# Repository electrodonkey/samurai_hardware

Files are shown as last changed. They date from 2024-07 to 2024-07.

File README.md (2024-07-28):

# samurai_hardware
Sumo Robot - Main Board

## Description

This repository contains the hardware design files for the main board of the HIRO 2024 sumo robot. The main board is responsible for the following tasks:

- Running the control algorithm
- Optical sensor reading
- Reading IMU data
- Communicating with the motor drivers

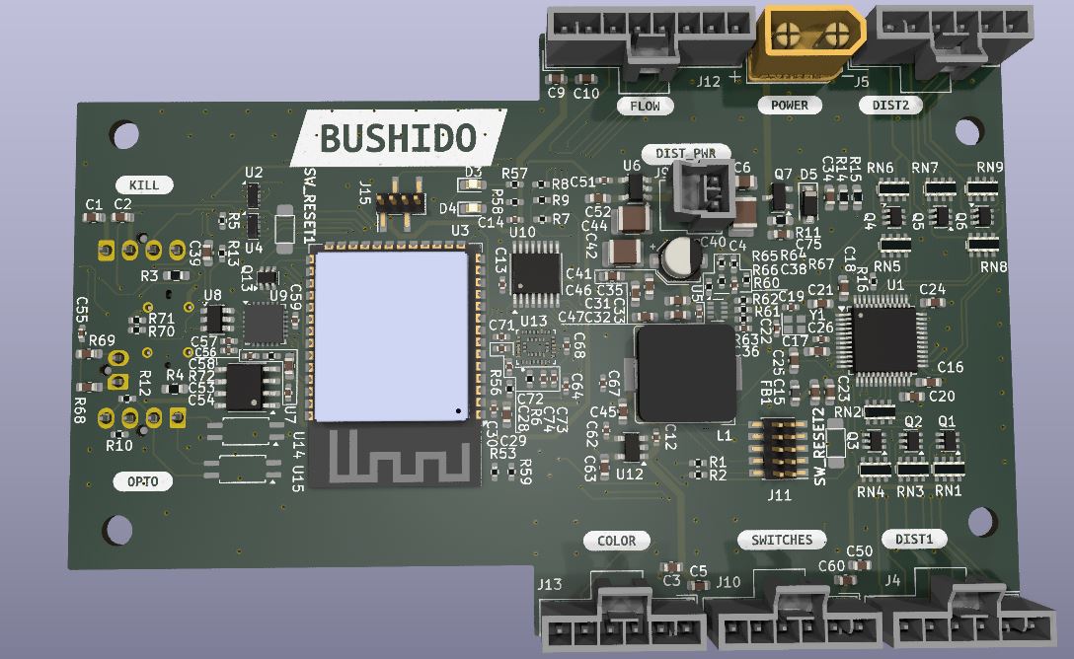
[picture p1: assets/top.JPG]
Top


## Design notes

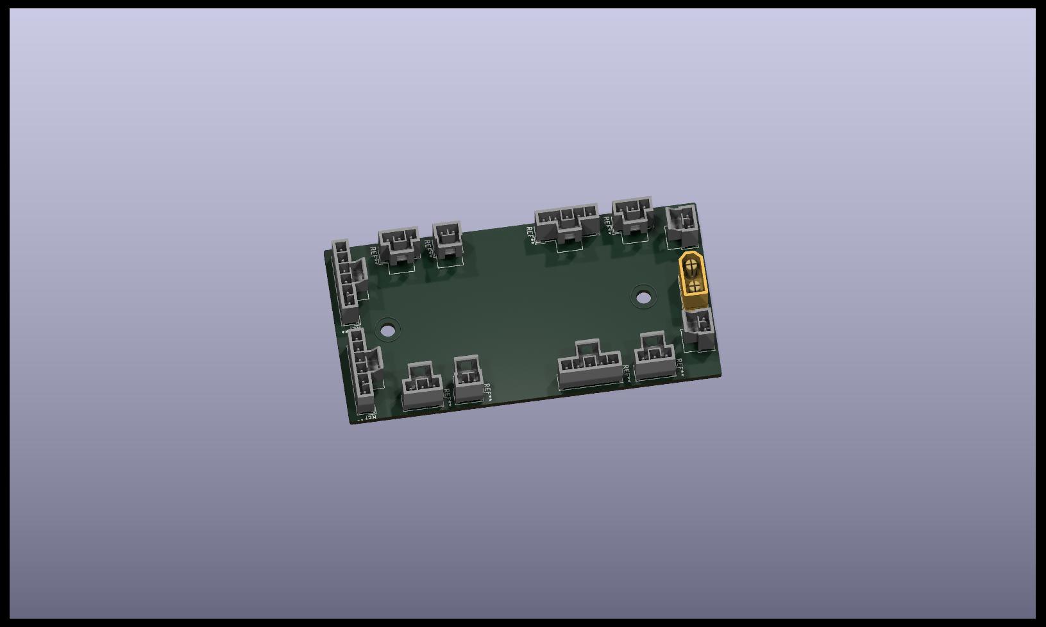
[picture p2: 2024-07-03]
samurai_connector_placement1.jpg

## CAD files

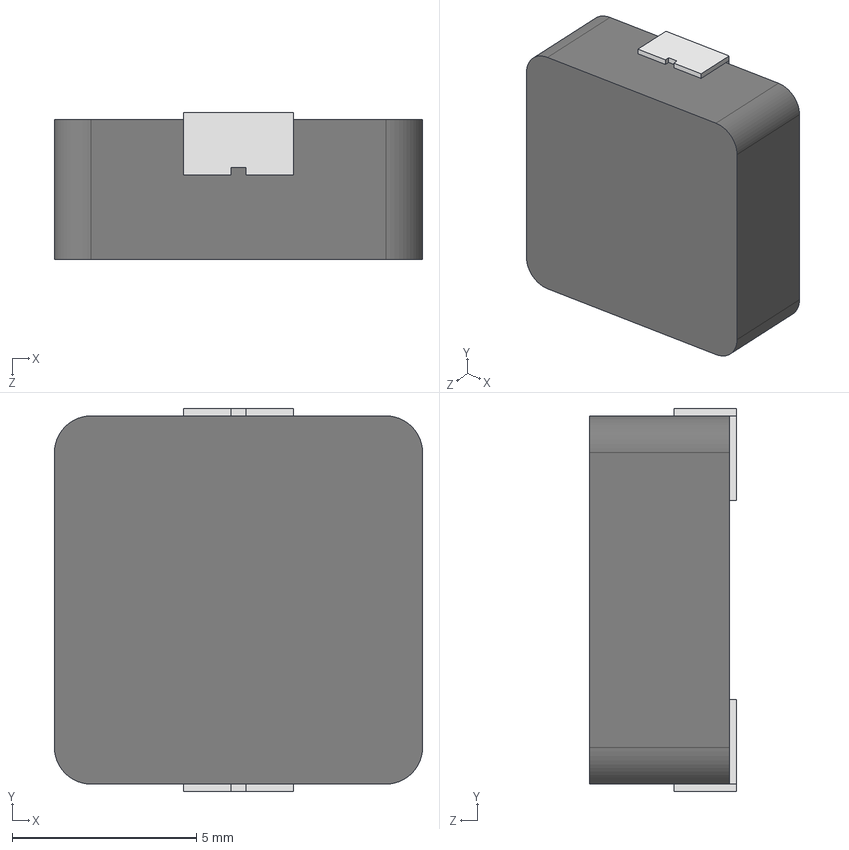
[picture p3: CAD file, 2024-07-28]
3d/User Library-SRP 1038A.step
10.0 x 10.4 x 4.00 mm

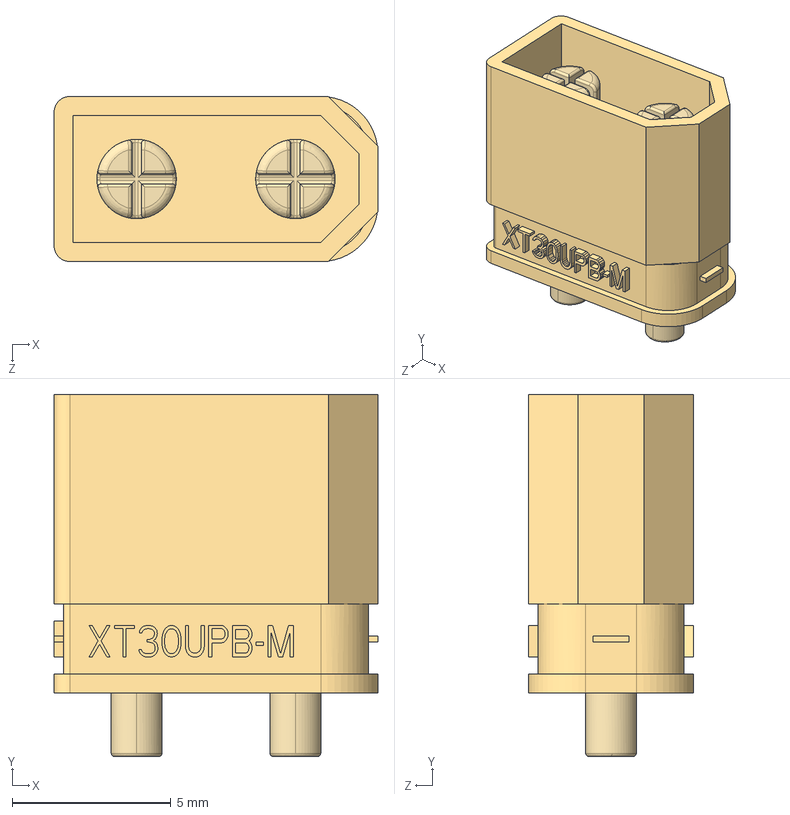
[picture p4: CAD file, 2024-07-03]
3d/amass-xt30upb-m.STEP
10.2 x 11.4 x 5.20 mm
XT30UPB-M
XT30UPB-M-PIN x 2

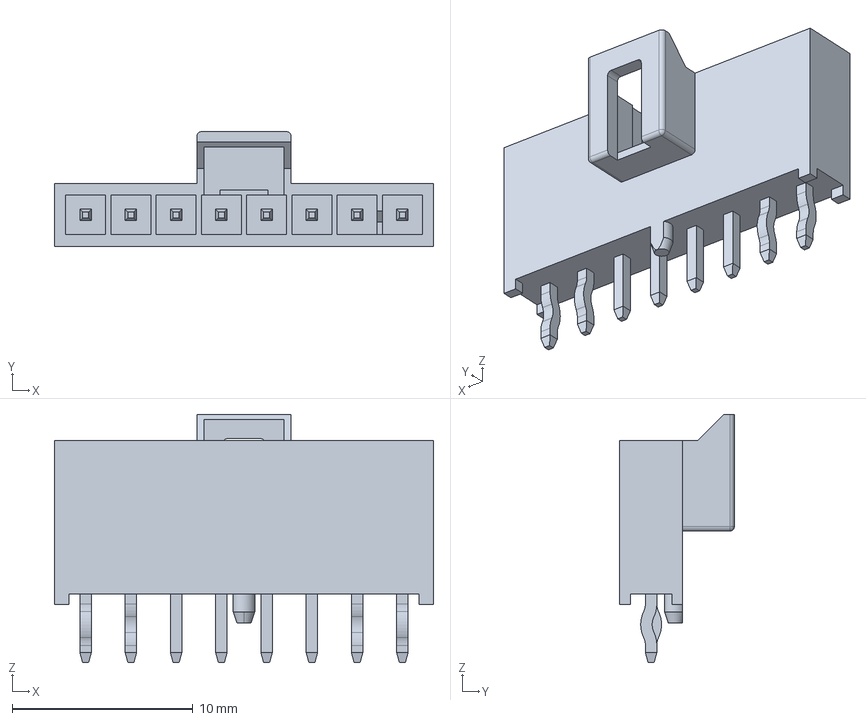
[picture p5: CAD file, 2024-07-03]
3d/molex_nanofit_1053091108.stp
20.9 x 6.34 x 13.7 mm

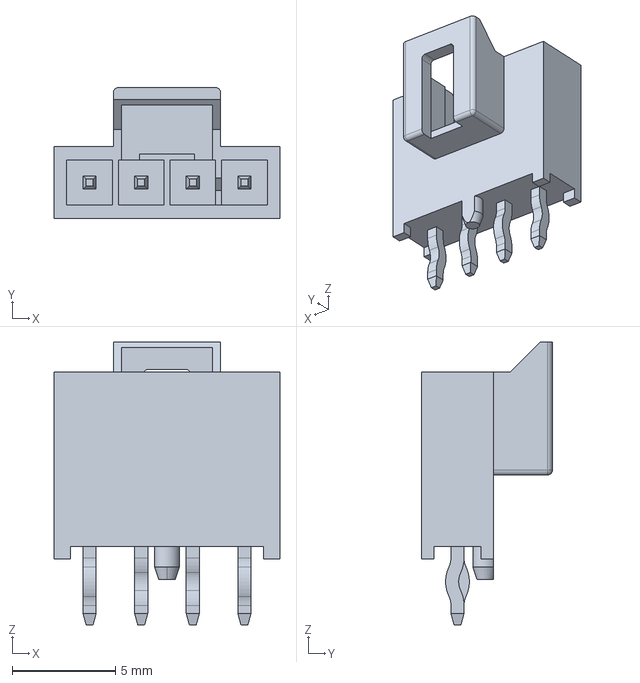
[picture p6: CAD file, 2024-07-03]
3d/molex_nanofit_1053091104.stp
10.9 x 6.34 x 13.7 mm

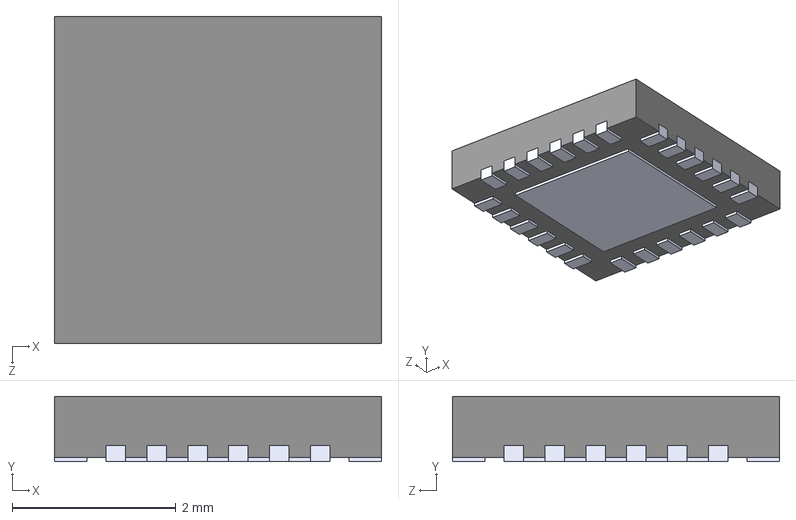
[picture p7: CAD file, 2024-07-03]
3d/CP2105-F01-GM.STEP
4.00 x 0.8 x 4.00 mm

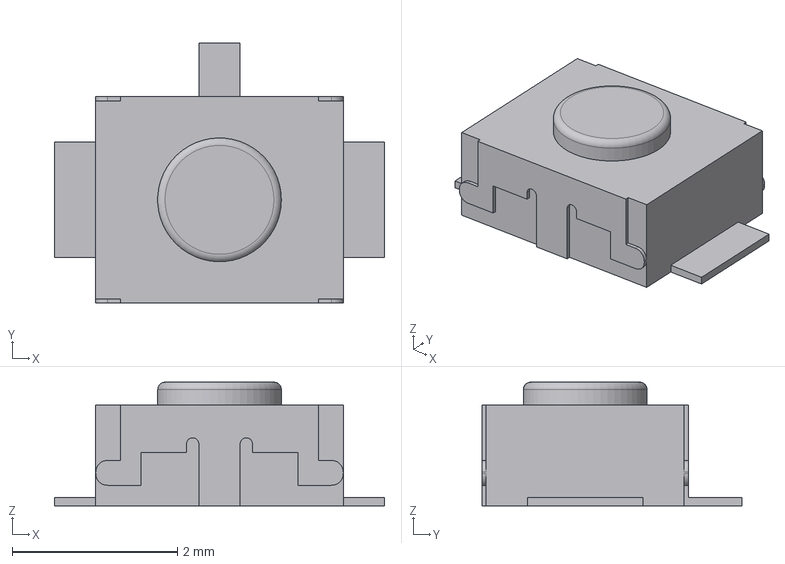
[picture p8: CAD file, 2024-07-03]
3d/TL1017AABF260QG.stp
4.00 x 3.15 x 1.50 mm

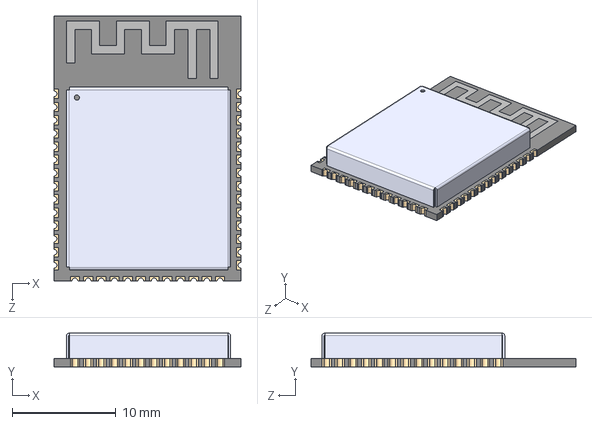
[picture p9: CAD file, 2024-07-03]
3d/ESP32-S3-WROOM-2-N16R8V--3DModel-STEP-510211.STEP
18.0 x 3.25 x 25.5 mm

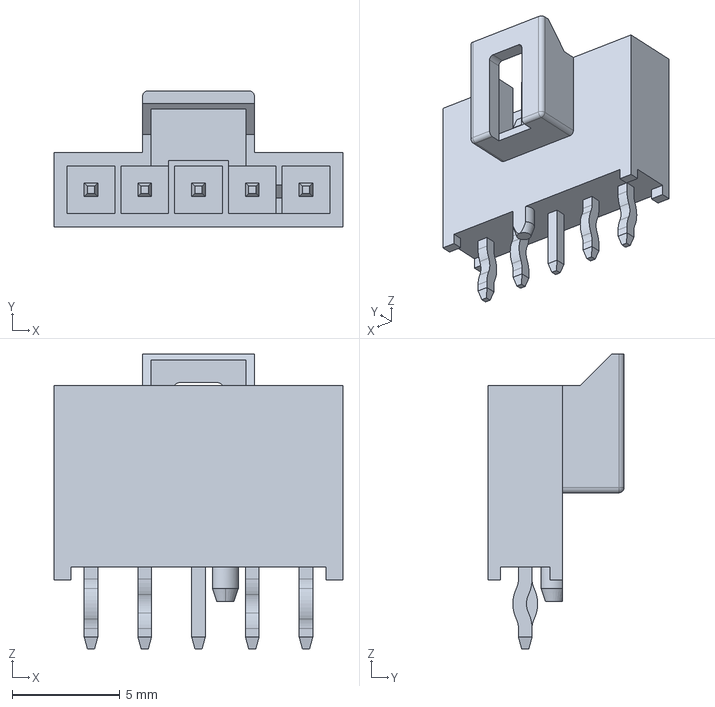
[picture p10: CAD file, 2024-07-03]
3d/molex_nanofit_1053091105.stp
13.4 x 6.34 x 13.7 mm

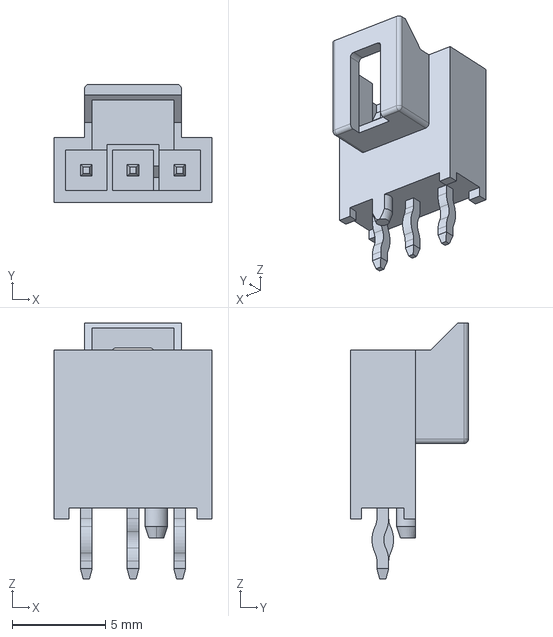
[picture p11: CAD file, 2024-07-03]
3d/molex_nanofit_1053091103.stp
8.44 x 6.34 x 13.7 mm

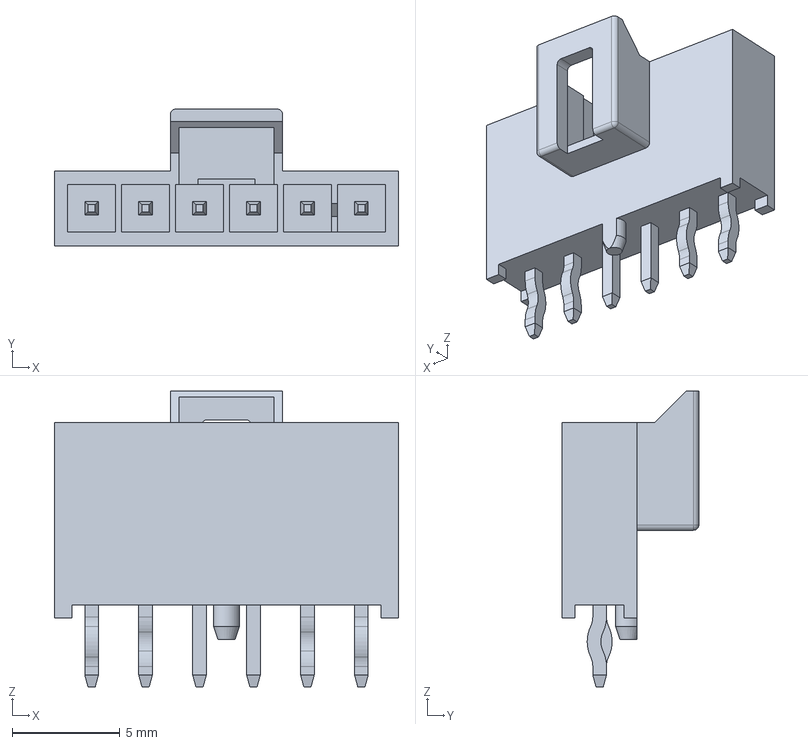
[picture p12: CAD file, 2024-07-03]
3d/molex_nanofit_1053091106.stp
15.9 x 6.34 x 13.7 mm

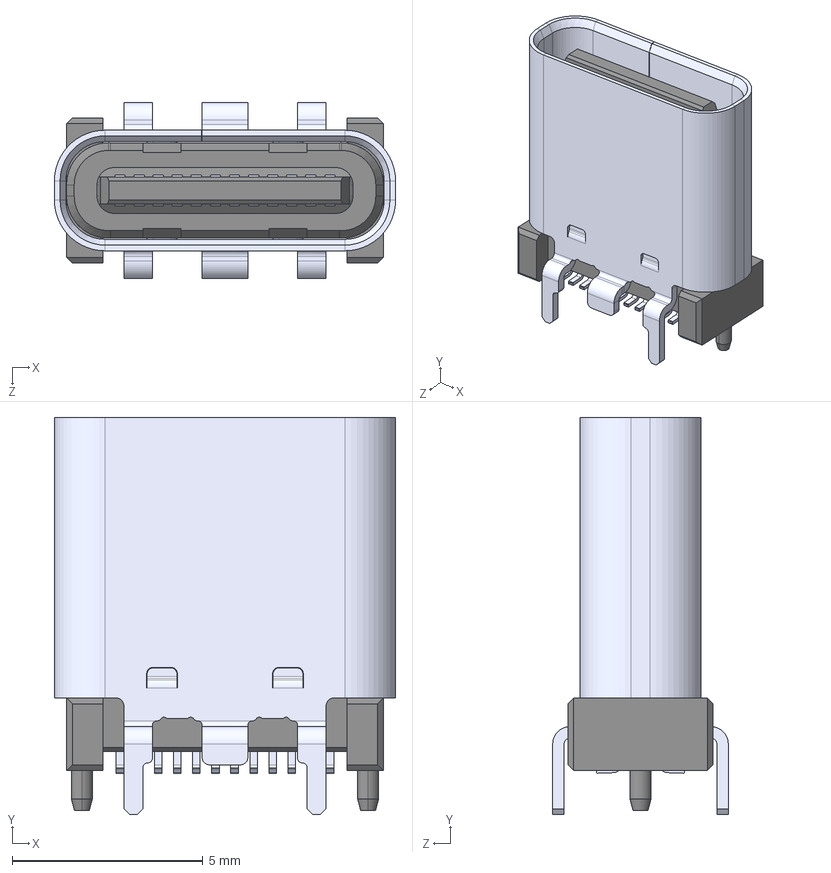
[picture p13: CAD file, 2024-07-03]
3d/USB4115-03-C--3DModel-STEP-56544.STEP
8.94 x 10.4 x 4.60 mm

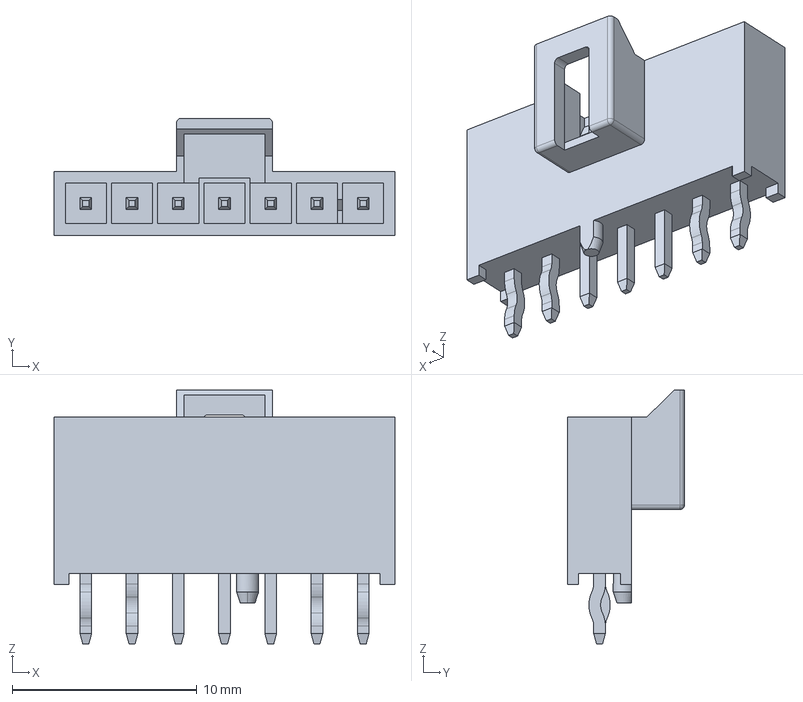
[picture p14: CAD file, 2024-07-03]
3d/molex_nanofit_1053091107.stp
18.4 x 6.34 x 13.7 mm

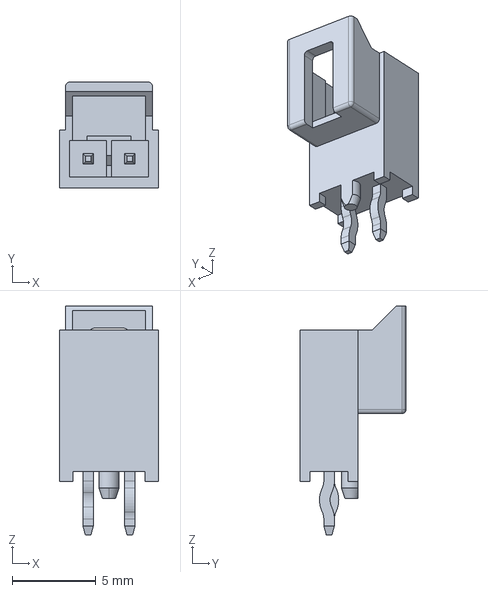
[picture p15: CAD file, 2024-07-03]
3d/molex_nanofit_x2_1053091102.stp
5.94 x 6.34 x 13.7 mm

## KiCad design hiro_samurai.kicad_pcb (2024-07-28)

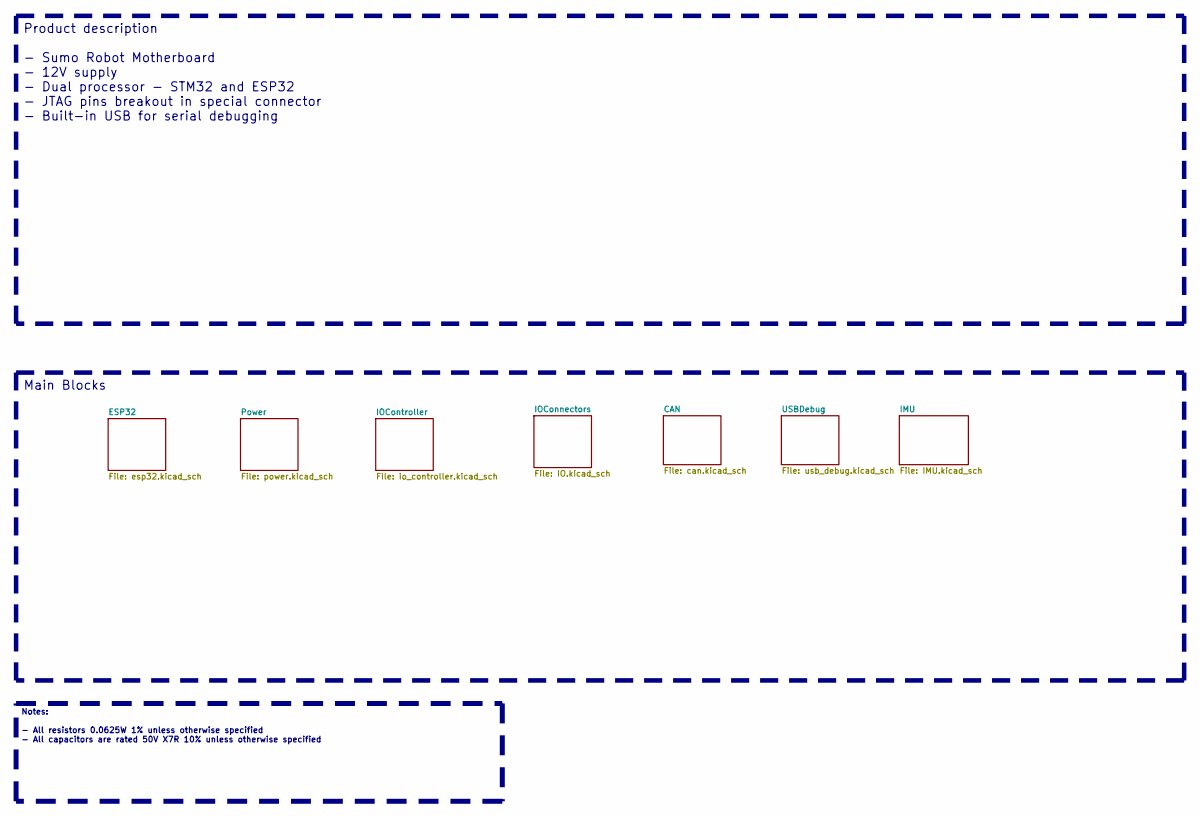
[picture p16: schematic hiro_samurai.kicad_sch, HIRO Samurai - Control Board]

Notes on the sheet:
Product description - Sumo Robot Motherboard - 12V supply - Dual processor - STM32 and ESP32 - JTAG pins breakout in special connector - Built-in USB for serial debugging
Notes: - All resistors 0.0625W 1% unless otherwise specified - All capacitors are rated 50V X7R 10% unless otherwise specified
Main Blocks

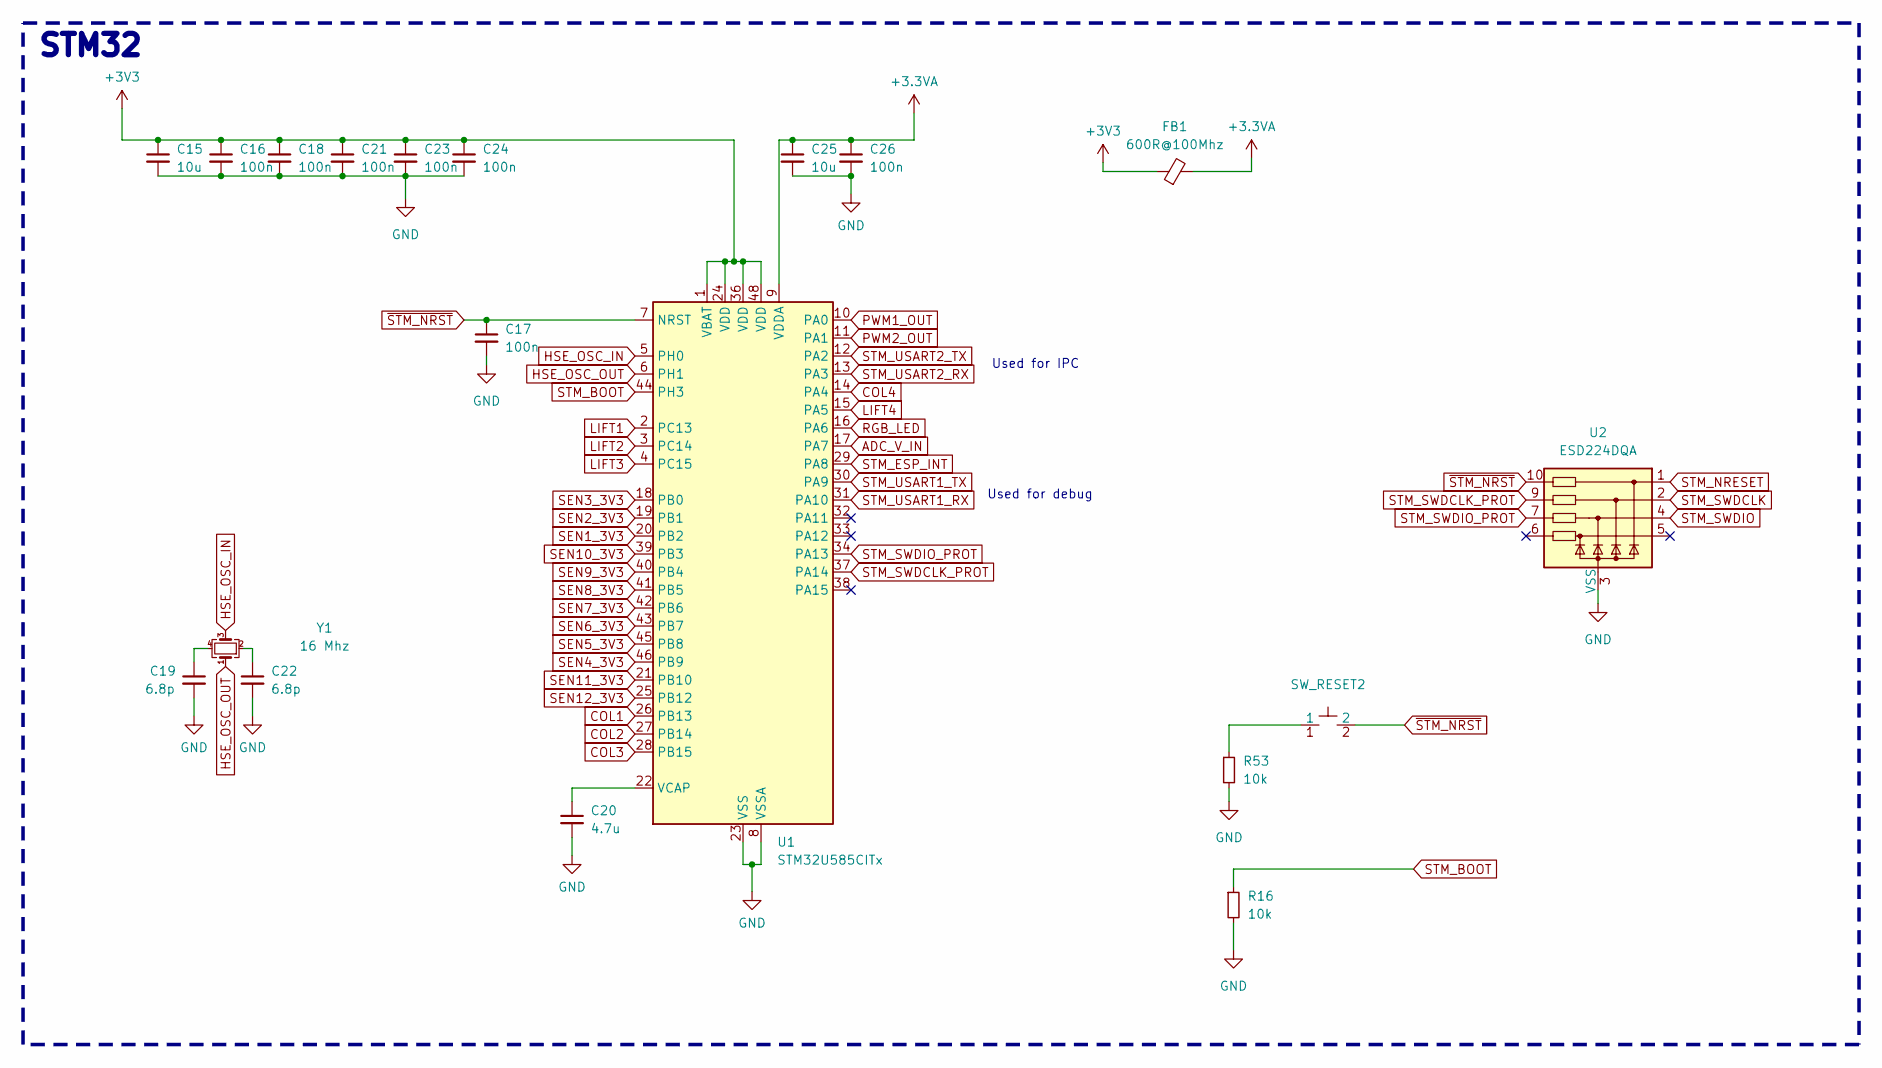
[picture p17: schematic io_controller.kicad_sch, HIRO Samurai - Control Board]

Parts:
C15, C25: 10u; C_0603_1608Metric_Pad1.08x0.95mm_HandSolder
C16, C18, C21, C23, C24, C26: 100n; C_0603_1608Metric_Pad1.08x0.95mm_HandSolder
C17: 100n; C_0402_1005Metric_Pad0.74x0.62mm_HandSolder
C19, C22: 6.8p; C_0402_1005Metric_Pad0.74x0.62mm_HandSolder
C20: 4.7u; C_0603_1608Metric_Pad1.08x0.95mm_HandSolder
FB1: 600R@100Mhz; L_0603_1608Metric_Pad1.05x0.95mm_HandSolder
R16, R53: 10k; R_0402_1005Metric_Pad0.72x0.64mm_HandSolder
SW_RESET2: TL1017AABF160QG
U1: STM32U585CITx; LQFP-48_7x7mm_P0.5mm
U2: ESD224DQA; Diodes_UDFN-10_1.0x2.5mm_P0.5mm
Y1: 16 Mhz; Crystal_SMD_2016-4Pin_2.0x1.6mm

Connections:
+3.3VA: C25.1, C26.1, FB1.2, U1.9 (VDDA)
+3V3: C15.1, C16.1, C18.1, C21.1, C23.1, C24.1, FB1.1, U1.1 (VBAT), U1.24 (VDD), U1.36 (VDD), U1.48 (VDD); also elsewhere on the board
ADC_V_IN: U1.17 (PA7); also elsewhere on the board
COL1: U1.26 (PB13); also elsewhere on the board
COL2: U1.27 (PB14); also elsewhere on the board
COL3: U1.28 (PB15); also elsewhere on the board
COL4: U1.14 (PA4); also elsewhere on the board
GND: C15.2, C16.2, C17.2, C18.2, C19.2, C20.2, C21.2, C22.2, C23.2, C24.2, C25.2, C26.2, R16.2, R53.2, U1.8 (VSSA), U1.23 (VSS), U1.35 (VSS), U1.47 (VSS), U2.3 (VSS), U2.8 (VSS); also elsewhere on the board
HSE_OSC_IN: U1.5 (PH0), Y1.3
HSE_OSC_OUT: U1.6 (PH1), Y1.1
LIFT1: U1.2 (PC13); also elsewhere on the board
LIFT2: U1.3 (PC14); also elsewhere on the board
LIFT3: U1.4 (PC15); also elsewhere on the board
LIFT4: U1.15 (PA5); also elsewhere on the board
unnamed: C19.1, Y1.4
unnamed: C22.1, Y1.2
unnamed: R53.1, SW_RESET2.1
unnamed: C20.1, U1.22 (VCAP)
PWM1_OUT: U1.10 (PA0); also elsewhere on the board
PWM2_OUT: U1.11 (PA1); also elsewhere on the board
RGB_LED: U1.16 (PA6); also elsewhere on the board
SEN1_3V3: U1.20 (PB2); also elsewhere on the board
SEN2_3V3: U1.19 (PB1); also elsewhere on the board
SEN3_3V3: U1.18 (PB0); also elsewhere on the board
SEN4_3V3: U1.46 (PB9); also elsewhere on the board
SEN5_3V3: U1.45 (PB8); also elsewhere on the board
SEN6_3V3: U1.43 (PB7); also elsewhere on the board
SEN7_3V3: U1.42 (PB6); also elsewhere on the board
SEN8_3V3: U1.41 (PB5); also elsewhere on the board
SEN9_3V3: U1.40 (PB4); also elsewhere on the board
SEN10_3V3: U1.39 (PB3); also elsewhere on the board
SEN11_3V3: U1.21 (PB10); also elsewhere on the board
SEN12_3V3: U1.25 (PB12); also elsewhere on the board
STM_BOOT: R16.1, U1.44 (PH3)
STM_ESP_INT: U1.29 (PA8); also elsewhere on the board
STM_NRESET: U2.1; also elsewhere on the board
STM_SWDCLK: U2.2; also elsewhere on the board
STM_SWDCLK_PROT: U1.37 (PA14), U2.9
STM_SWDIO: U2.4; also elsewhere on the board
STM_SWDIO_PROT: U1.34 (PA13), U2.7
STM_USART1_RX: U1.31 (PA10); also elsewhere on the board
STM_USART1_TX: U1.30 (PA9); also elsewhere on the board
STM_USART2_RX: U1.13 (PA3); also elsewhere on the board
STM_USART2_TX: U1.12 (PA2); also elsewhere on the board
~STM_NRST: C17.1, SW_RESET2.2, U1.7 (NRST), U2.10

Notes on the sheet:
Used for IPC
Used for debug
STM32

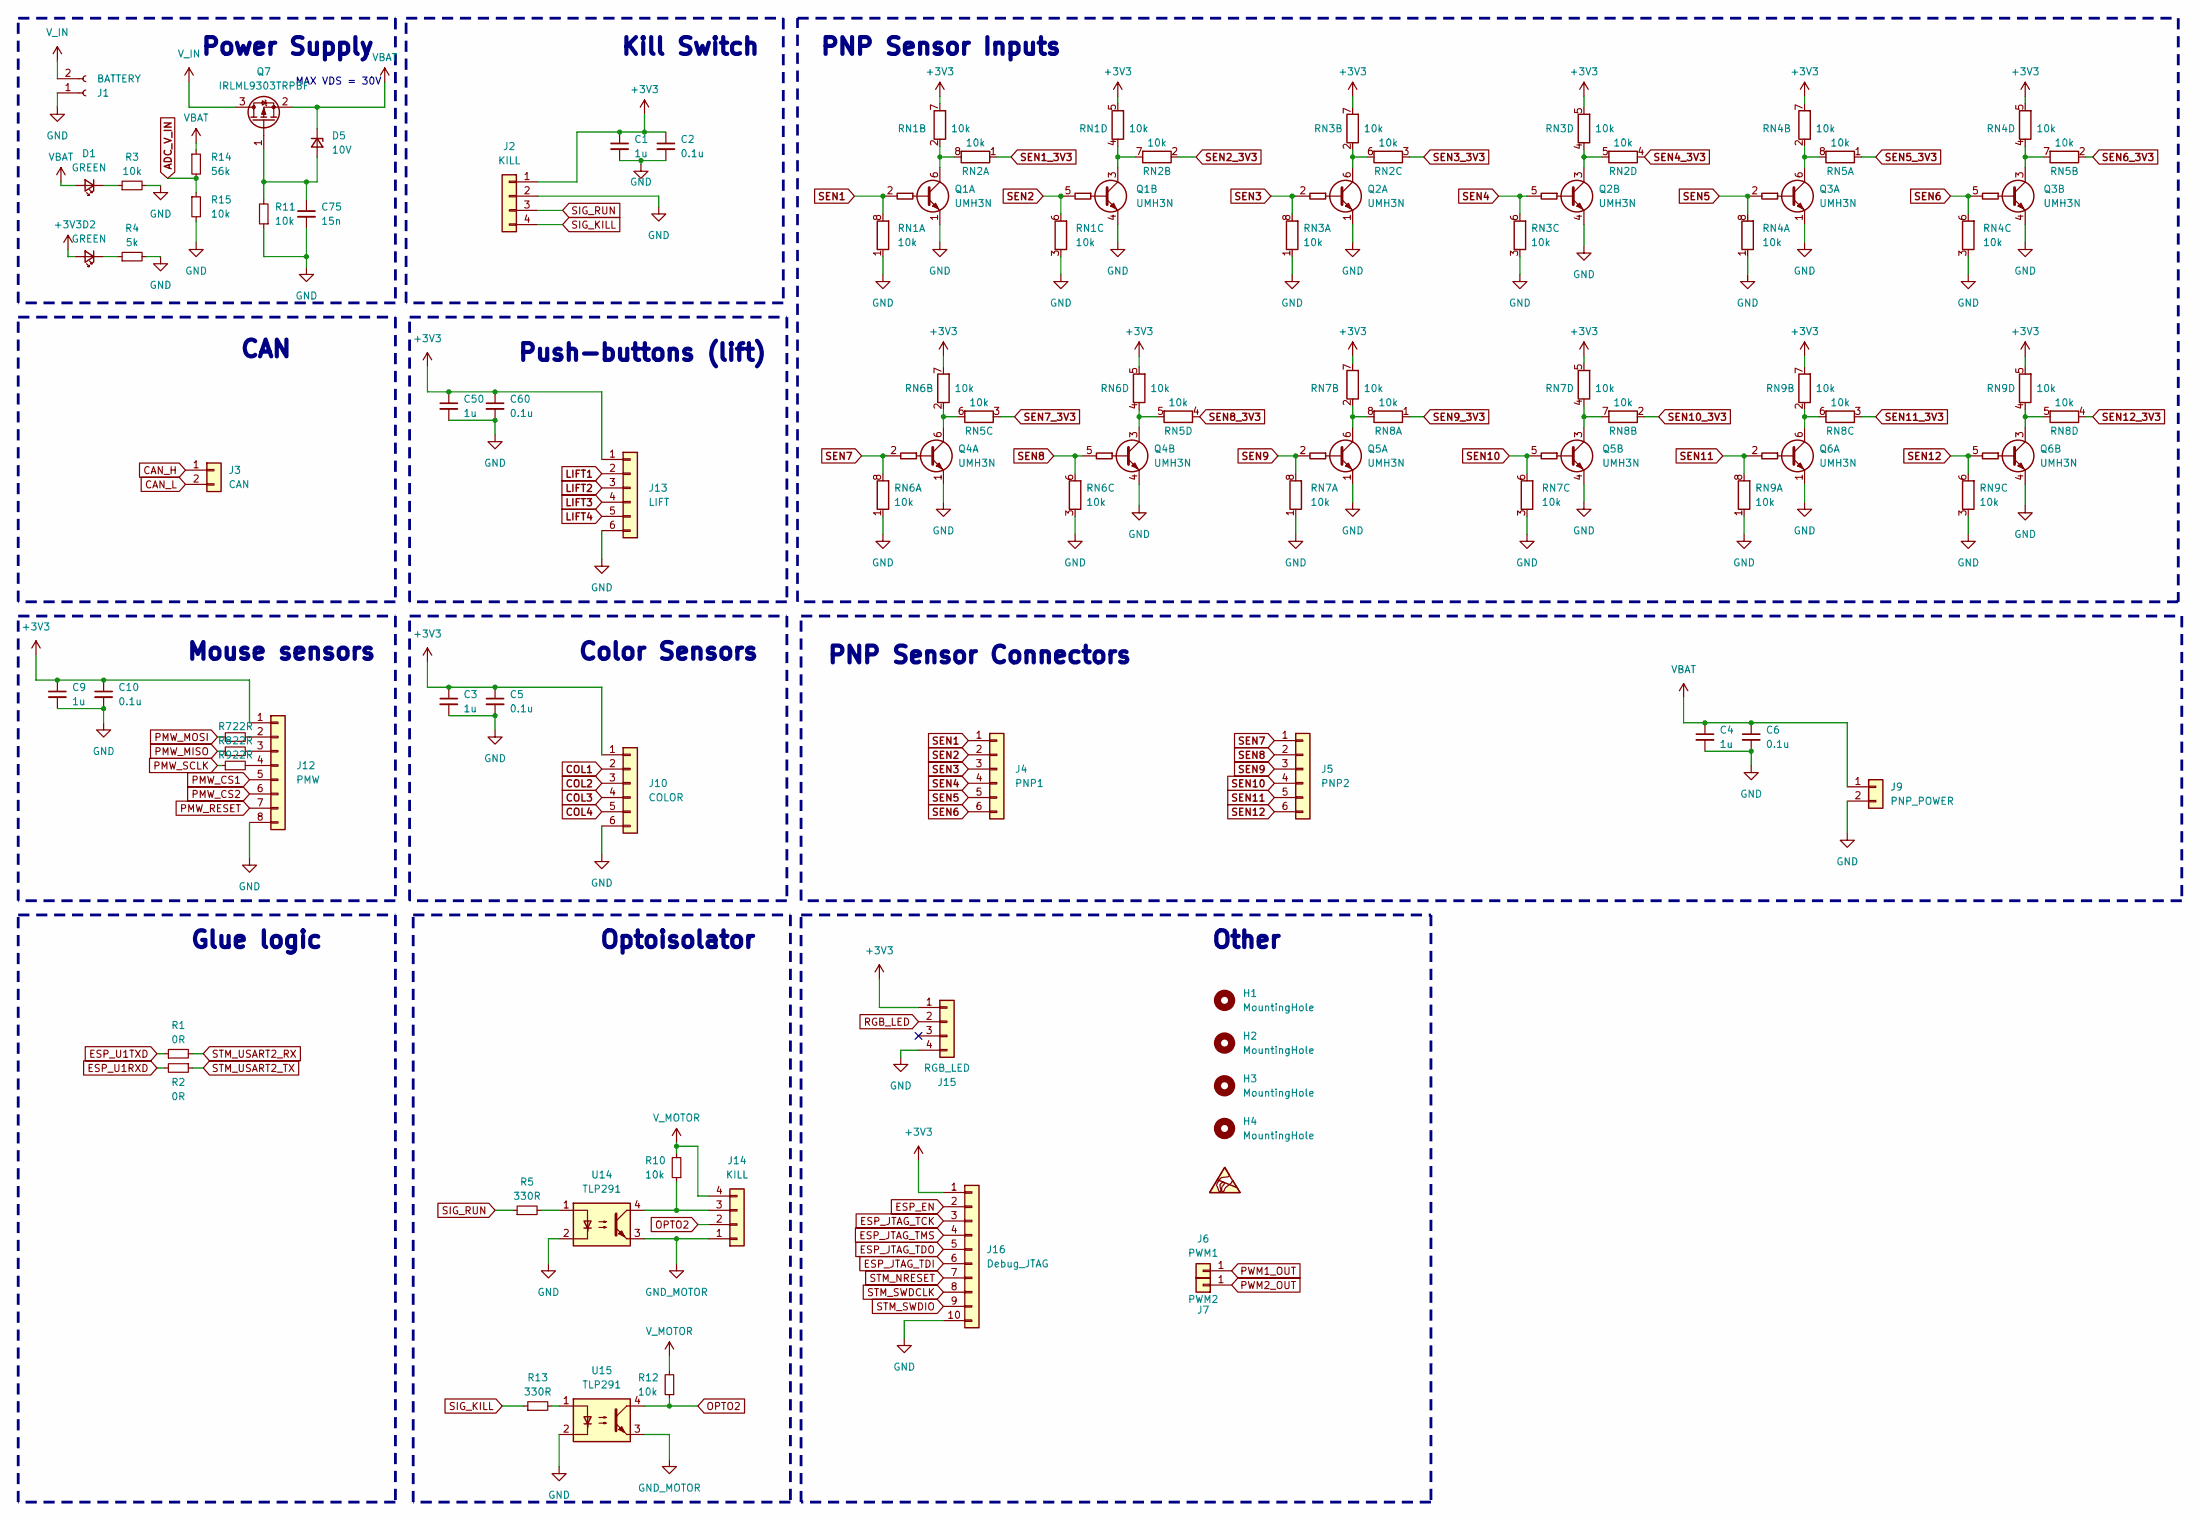
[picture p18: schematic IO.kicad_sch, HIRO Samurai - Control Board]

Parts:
C1, C3, C9, C50: 1u; C_0603_1608Metric
C2, C5, C10, C60: 0.1u; C_0603_1608Metric
C4: 1u; C_1210_3225Metric_Pad1.33x2.70mm_HandSolder
C6: 0.1u; C_0805_2012Metric_Pad1.18x1.45mm_HandSolder
C75: 15n; C_0603_1608Metric_Pad1.08x0.95mm_HandSolder
D1, D2: GREEN; LED_0603_1608Metric_Pad1.05x0.95mm_HandSolder
D5: 10V; D_SOD-123
H1, H2, H3, H4: MountingHole; MountingHole_3.2mm_M3
J1: BATTERY; AMASS_XT30U-M_1x02_P5.0mm_Vertical
J2, J14: KILL; Molex_Nano-Fit_105309-xx04_1x04_P2.50mm_Vertical
J3: CAN; Molex_Nano-Fit_105309-xx02_1x02_P2.50mm_Vertical
J4: PNP1; Molex_Nano-Fit_105309-xx06_1x06_P2.50mm_Vertical
J5: PNP2; Molex_Nano-Fit_105309-xx06_1x06_P2.50mm_Vertical
J6: PWM1; SolderWirePad_1x01_SMD_1x2mm
J7: PWM2; SolderWirePad_1x01_SMD_1x2mm
J9: PNP_POWER; Molex_Nano-Fit_105309-xx02_1x02_P2.50mm_Vertical
J10: COLOR; Molex_Nano-Fit_105309-xx06_1x06_P2.50mm_Vertical
J12: PMW; Molex_Nano-Fit_105309-xx08_1x08_P2.50mm_Vertical
J13: LIFT; Molex_Nano-Fit_105309-xx06_1x06_P2.50mm_Vertical
J15: RGB_LED; PinHeader_1x04_P1.27mm_Vertical_SMD_Pin1Left
J16: Debug_JTAG; PinHeader_2x05_P1.27mm_Vertical_SMD
Q1, Q2, Q3, Q4, Q5, Q6: UMH3N; SOT-363_SC-70-6
Q7: IRLML9303TRPBF; SOT-23
R1, R2: 0R; R_0402_1005Metric_Pad0.72x0.64mm_HandSolder
R3, R11, R15: 10k; R_0603_1608Metric_Pad0.98x0.95mm_HandSolder
R4: 5k; R_0603_1608Metric_Pad0.98x0.95mm_HandSolder
R5, R13: 330R; R_0402_1005Metric_Pad0.72x0.64mm_HandSolder
R7, R8, R9: 22R; R_0402_1005Metric_Pad0.72x0.64mm_HandSolder
R10, R12: 10k; R_0402_1005Metric_Pad0.72x0.64mm_HandSolder
R14: 56k; R_0603_1608Metric_Pad0.98x0.95mm_HandSolder
RN1, RN2, RN3, RN4, RN5, RN6, RN7, RN8, RN9: 10k; R_Array_Concave_4x0603
U14, U15: TLP291; SOIC-4_4.55x2.6mm_P1.27mm

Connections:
+3V3: C1.1, C2.1, C3.1, C5.1, C9.1, C10.1, C50.1, C60.1, D2.2 (A), J2.1, J10.1, J12.1, J13.1, J15.1, J16.1, RN1.5 (R4.2), RN1.7 (R2.2), RN3.5 (R4.2), RN3.7 (R2.2), RN4.5 (R4.2), RN4.7 (R2.2), RN6.5 (R4.2), RN6.7 (R2.2), RN7.5 (R4.2), RN7.7 (R2.2), RN9.5 (R4.2), RN9.7 (R2.2); also elsewhere on the board
ADC_V_IN: R14.2, R15.1; also elsewhere on the board
CAN_H: J3.1; also elsewhere on the board
CAN_L: J3.2; also elsewhere on the board
COL1: J10.2; also elsewhere on the board
COL2: J10.3; also elsewhere on the board
COL3: J10.4; also elsewhere on the board
COL4: J10.5; also elsewhere on the board
ESP_EN: J16.2; also elsewhere on the board
ESP_JTAG_TCK: J16.3; also elsewhere on the board
ESP_JTAG_TDI: J16.6; also elsewhere on the board
ESP_JTAG_TDO: J16.5; also elsewhere on the board
ESP_JTAG_TMS: J16.4; also elsewhere on the board
ESP_U1RXD: R2.2; also elsewhere on the board
ESP_U1TXD: R1.1; also elsewhere on the board
GND: C1.2, C2.2, C3.2, C4.2, C5.2, C6.2, C9.2, C10.2, C50.2, C60.2, C75.2, J1.1, J2.2, J9.2, J10.6, J12.8, J13.6, J15.4, J16.10, Q1.1 (E1), Q1.4 (E2), Q2.1 (E1), Q2.4 (E2), Q3.1 (E1), Q3.4 (E2), Q4.1 (E1), Q4.4 (E2), Q5.1 (E1), Q5.4 (E2), Q6.1 (E1), Q6.4 (E2), R3.2, R4.2, R11.1, R15.2, RN1.1 (R1.1), RN1.3 (R3.1), RN3.1 (R1.1), RN3.3 (R3.1), RN4.1 (R1.1), RN4.3 (R3.1), RN6.1 (R1.1), RN6.3 (R3.1), RN7.1 (R1.1), RN7.3 (R3.1), RN9.1 (R1.1), RN9.3 (R3.1), U14.2, U15.2; also elsewhere on the board
GND_MOTOR: J14.1, U14.3, U15.3
LIFT1: J13.2; also elsewhere on the board
LIFT2: J13.3; also elsewhere on the board
LIFT3: J13.4; also elsewhere on the board
LIFT4: J13.5; also elsewhere on the board
unnamed: D1.1 (K), R3.1
unnamed: D2.1 (K), R4.1
unnamed: C75.1, D5.2 (A), Q7.1 (G), R11.2
unnamed: J12.2, R7.2
unnamed: J12.3, R8.2
unnamed: J12.4, R9.2
unnamed: J14.3, R10.1, U14.4
unnamed: Q1.6 (C1), RN1.2 (R2.1), RN2.8 (R1.2)
unnamed: Q1.3 (C2), RN1.4 (R4.1), RN2.7 (R2.2)
unnamed: Q2.6 (C1), RN2.6 (R3.2), RN3.2 (R2.1)
unnamed: Q2.3 (C2), RN2.5 (R4.2), RN3.4 (R4.1)
unnamed: Q3.6 (C1), RN4.2 (R2.1), RN5.8 (R1.2)
unnamed: Q3.3 (C2), RN4.4 (R4.1), RN5.7 (R2.2)
unnamed: Q4.6 (C1), RN5.6 (R3.2), RN6.2 (R2.1)
unnamed: Q4.3 (C2), RN5.5 (R4.2), RN6.4 (R4.1)
unnamed: Q5.6 (C1), RN7.2 (R2.1), RN8.8 (R1.2)
unnamed: Q5.3 (C2), RN7.4 (R4.1), RN8.7 (R2.2)
unnamed: Q6.6 (C1), RN8.6 (R3.2), RN9.2 (R2.1)
unnamed: Q6.3 (C2), RN8.5 (R4.2), RN9.4 (R4.1)
unnamed: R5.2, U14.1
unnamed: R13.2, U15.1
OPTO2: J14.2, R12.1, U15.4
PMW_CS1: J12.5; also elsewhere on the board
PMW_CS2: J12.6; also elsewhere on the board
PMW_MISO: R8.1; also elsewhere on the board
PMW_MOSI: R7.1; also elsewhere on the board
PMW_RESET: J12.7; also elsewhere on the board
PMW_SCLK: R9.1; also elsewhere on the board
PWM1_OUT: J6.1; also elsewhere on the board
PWM2_OUT: J7.1; also elsewhere on the board
RGB_LED: J15.2; also elsewhere on the board
SEN1: J4.1, Q1.2 (B1), RN1.8 (R1.2)
SEN1_3V3: RN2.1 (R1.1); also elsewhere on the board
SEN2: J4.2, Q1.5 (B2), RN1.6 (R3.2)
SEN2_3V3: RN2.2 (R2.1); also elsewhere on the board
SEN3: J4.3, Q2.2 (B1), RN3.8 (R1.2)
SEN3_3V3: RN2.3 (R3.1); also elsewhere on the board
SEN4: J4.4, Q2.5 (B2), RN3.6 (R3.2)
SEN4_3V3: RN2.4 (R4.1); also elsewhere on the board
SEN5: J4.5, Q3.2 (B1), RN4.8 (R1.2)
SEN5_3V3: RN5.1 (R1.1); also elsewhere on the board
SEN6: J4.6, Q3.5 (B2), RN4.6 (R3.2)
SEN6_3V3: RN5.2 (R2.1); also elsewhere on the board
SEN7: J5.1, Q4.2 (B1), RN6.8 (R1.2)
SEN7_3V3: RN5.3 (R3.1); also elsewhere on the board
SEN8: J5.2, Q4.5 (B2), RN6.6 (R3.2)
SEN8_3V3: RN5.4 (R4.1); also elsewhere on the board
SEN9: J5.3, Q5.2 (B1), RN7.8 (R1.2)
SEN9_3V3: RN8.1 (R1.1); also elsewhere on the board
SEN10: J5.4, Q5.5 (B2), RN7.6 (R3.2)
SEN10_3V3: RN8.2 (R2.1); also elsewhere on the board
SEN11: J5.5, Q6.2 (B1), RN9.8 (R1.2)
SEN11_3V3: RN8.3 (R3.1); also elsewhere on the board
SEN12: J5.6, Q6.5 (B2), RN9.6 (R3.2)
SEN12_3V3: RN8.4 (R4.1); also elsewhere on the board
SIG_KILL: J2.4, R13.1; also elsewhere on the board
SIG_RUN: J2.3, R5.1; also elsewhere on the board
STM_NRESET: J16.7; also elsewhere on the board
STM_SWDCLK: J16.8; also elsewhere on the board
STM_SWDIO: J16.9; also elsewhere on the board
STM_USART2_RX: R1.2; also elsewhere on the board
STM_USART2_TX: R2.1; also elsewhere on the board
VBAT: C4.1, C6.1, D1.2 (A), D5.1 (K), J9.1, Q7.2 (S), R14.1; also elsewhere on the board
V_IN: J1.2, Q7.3 (D)
V_MOTOR: J14.4, R10.2, R12.2

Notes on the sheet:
Optoisolator
Kill Switch
Power Supply
Glue logic
PNP Sensor Inputs
Color Sensors
Other
CAN
PNP Sensor Connectors
Push-buttons (lift)
MAX VDS = 30V
Mouse sensors

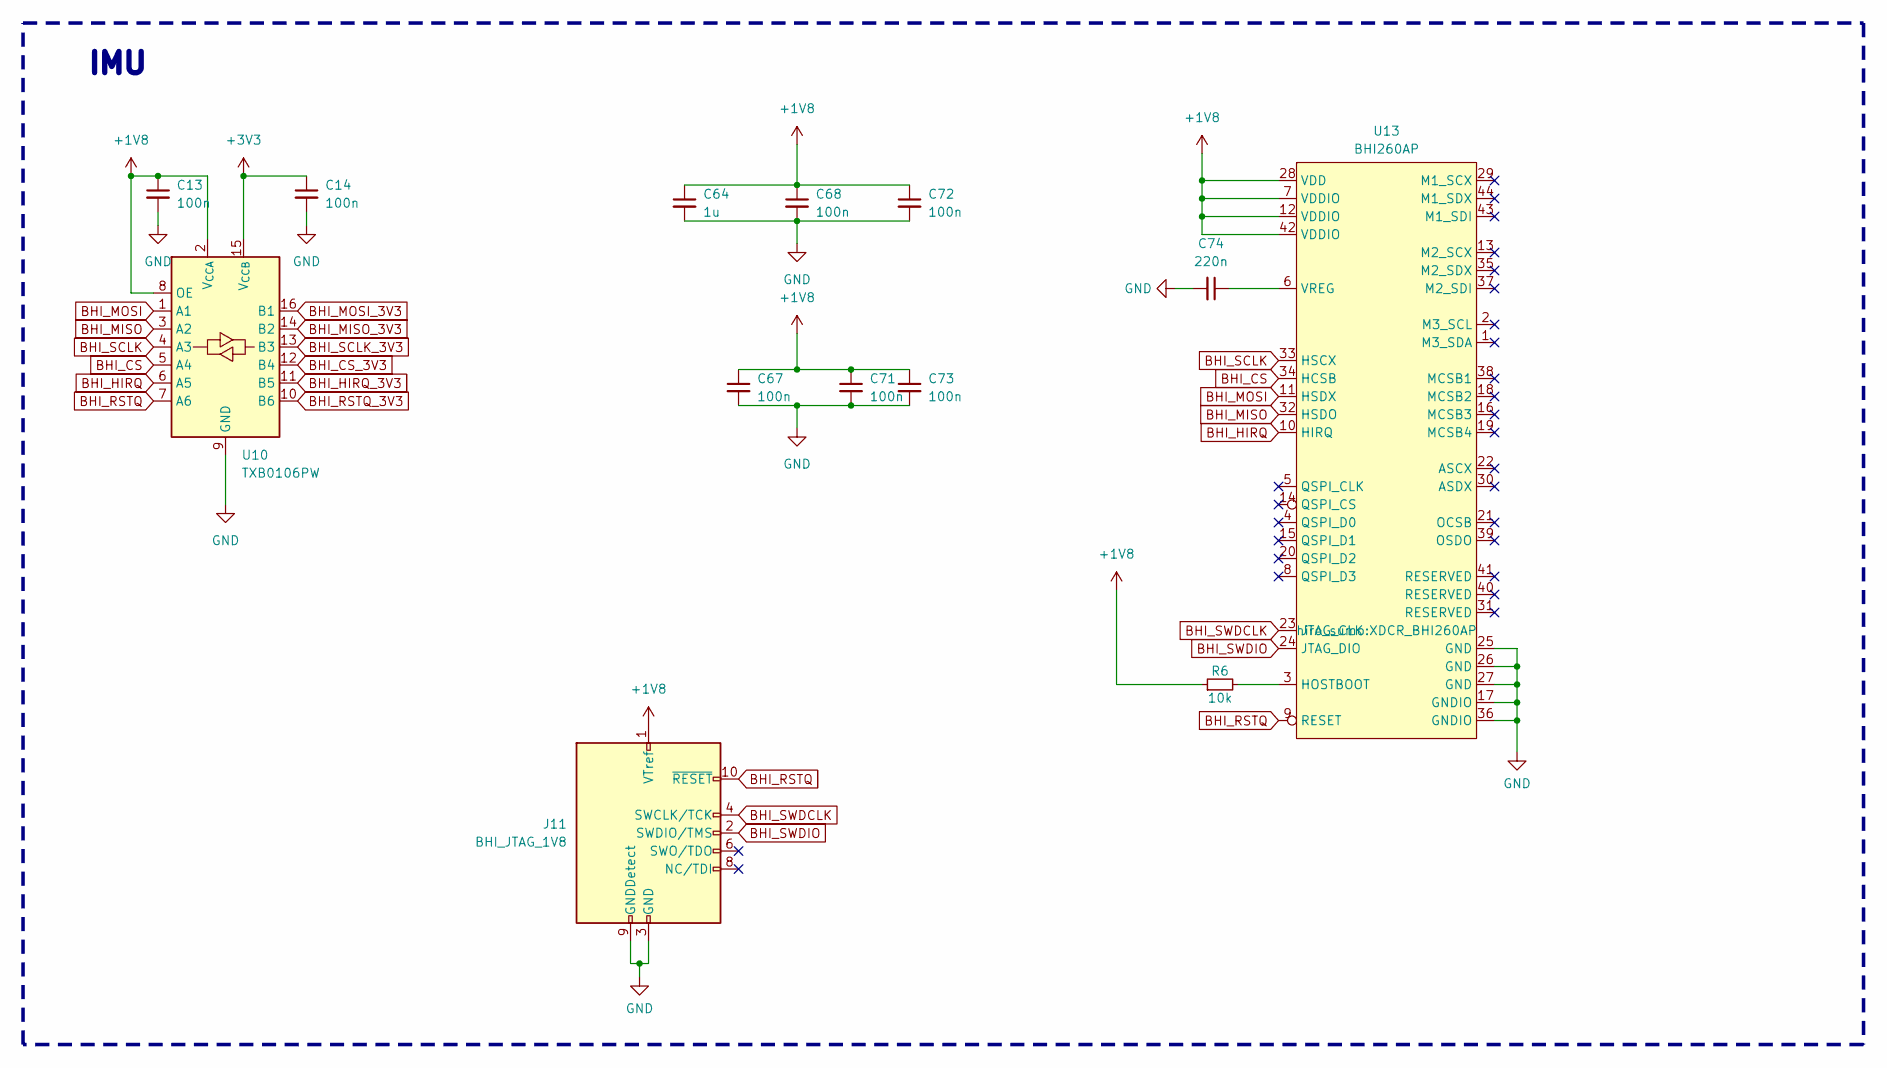
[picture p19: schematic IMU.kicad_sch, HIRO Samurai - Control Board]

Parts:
C13, C14, C67, C68, C71, C72, C73: 100n; C_0402_1005Metric_Pad0.74x0.62mm_HandSolder
C64: 1u; C_0402_1005Metric_Pad0.74x0.62mm_HandSolder
C74: 220n; C_0402_1005Metric_Pad0.74x0.62mm_HandSolder
J11: BHI_JTAG_1V8; PinHeader_2x05_P1.27mm_Vertical_SMD
R6: 10k; R_0402_1005Metric_Pad0.72x0.64mm_HandSolder
U10: TXB0106PW; TSSOP-16_4.4x5mm_P0.65mm
U13: BHI260AP; XDCR_BHI260AP

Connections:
+1V8: C13.1, C64.1, C67.1, C68.1, C71.1, C72.1, C73.1, J11.1 (VTref), R6.1, U10.2 (V_{CCA}), U10.8 (OE), U13.7 (VDDIO), U13.12 (VDDIO), U13.28 (VDD), U13.42 (VDDIO); also elsewhere on the board
+3V3: C14.1, U10.15 (V_{CCB}); also elsewhere on the board
BHI_CS: U10.5 (A4), U13.34 (HCSB)
BHI_CS_3V3: U10.12 (B4); also elsewhere on the board
BHI_HIRQ: U10.6 (A5), U13.10 (HIRQ)
BHI_HIRQ_3V3: U10.11 (B5); also elsewhere on the board
BHI_MISO: U10.3 (A2), U13.32 (HSDO)
BHI_MISO_3V3: U10.14 (B2); also elsewhere on the board
BHI_MOSI: U10.1 (A1), U13.11 (HSDX)
BHI_MOSI_3V3: U10.16 (B1); also elsewhere on the board
BHI_RSTQ: J11.10 (~RESET), U10.7 (A6), U13.9 (RESET)
BHI_RSTQ_3V3: U10.10 (B6); also elsewhere on the board
BHI_SCLK: U10.4 (A3), U13.33 (HSCX)
BHI_SCLK_3V3: U10.13 (B3); also elsewhere on the board
BHI_SWDCLK: J11.4 (SWCLK/TCK), U13.23 (JTAG_CLK)
BHI_SWDIO: J11.2 (SWDIO/TMS), U13.24 (JTAG_DIO)
GND: C13.2, C14.2, C64.2, C67.2, C68.2, C71.2, C72.2, C73.2, C74.2, J11.3 (GND), J11.5 (GND), J11.9 (GNDDetect), U10.9 (GND), U13.17 (GNDIO), U13.25 (GND), U13.26 (GND), U13.27 (GND), U13.36 (GNDIO); also elsewhere on the board
unnamed: R6.2, U13.3 (HOSTBOOT)
unnamed: C74.1, U13.6 (VREG)

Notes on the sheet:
IMU

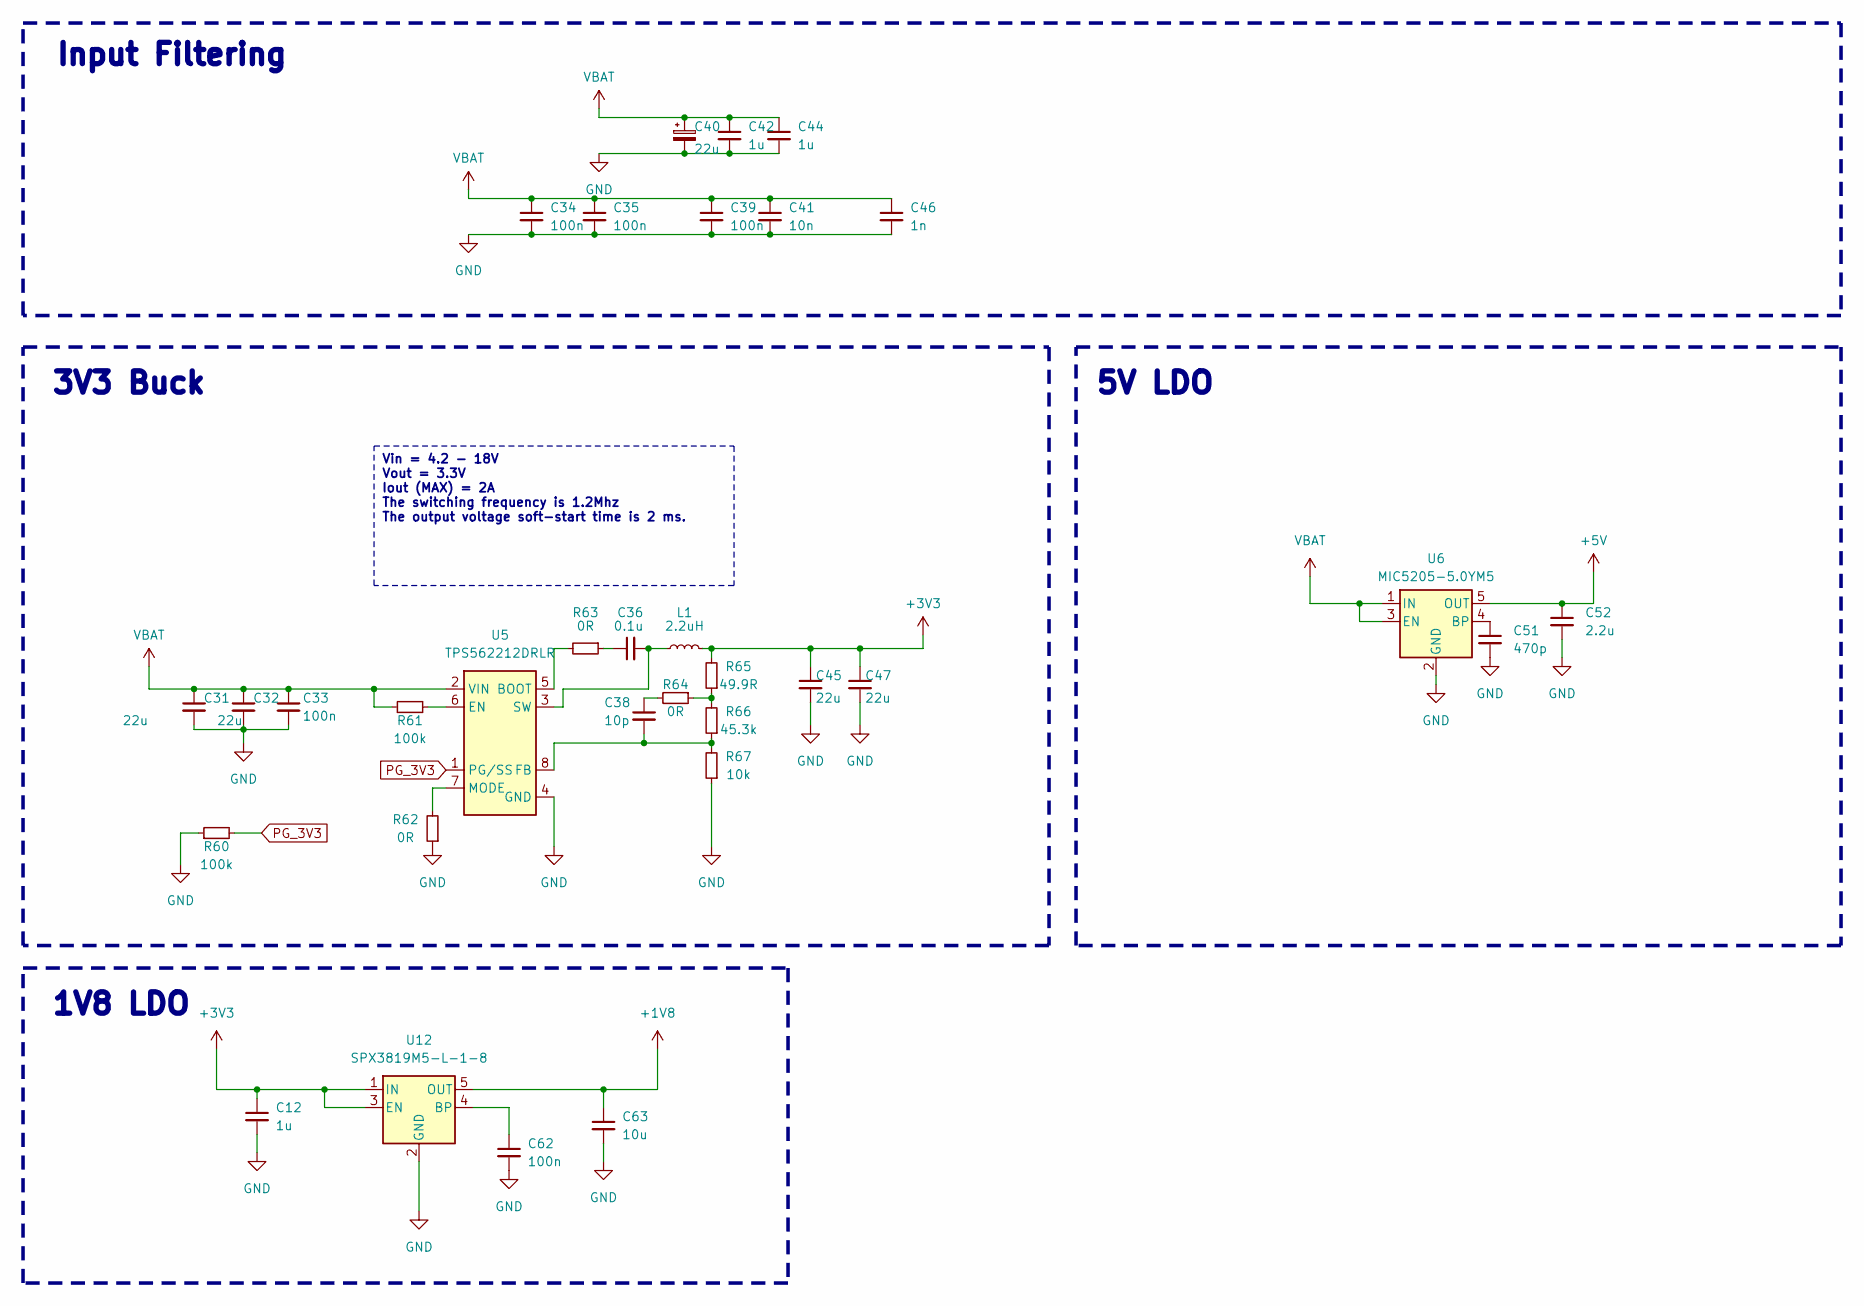
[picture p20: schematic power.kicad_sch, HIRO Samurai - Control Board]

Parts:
C12: 1u; C_0402_1005Metric_Pad0.74x0.62mm_HandSolder
C31, C32, C45, C47: 22u; C_0603_1608Metric_Pad1.08x0.95mm_HandSolder
C33, C62: 100n; C_0402_1005Metric_Pad0.74x0.62mm_HandSolder
C34, C35, C39: 100n; C_0603_1608Metric_Pad1.08x0.95mm_HandSolder
C36: 0.1u; C_0402_1005Metric_Pad0.74x0.62mm_HandSolder
C38: 10p; C_0402_1005Metric_Pad0.74x0.62mm_HandSolder
C40: 22u; CP_Elec_4x4.5
C41: 10n; C_0603_1608Metric_Pad1.08x0.95mm_HandSolder
C42, C44: 1u; C_1210_3225Metric_Pad1.33x2.70mm_HandSolder
C46: 1n; C_0603_1608Metric_Pad1.08x0.95mm_HandSolder
C51: 470p; C_0402_1005Metric_Pad0.74x0.62mm_HandSolder
C52: 2.2u; C_0603_1608Metric_Pad1.08x0.95mm_HandSolder
C63: 10u; C_0603_1608Metric_Pad1.08x0.95mm_HandSolder
L1: 2.2uH; L_Bourns_SRP1038C_10.0x10.0mm
R60, R61: 100k; R_0402_1005Metric_Pad0.72x0.64mm_HandSolder
R62, R63, R64: 0R; R_0402_1005Metric_Pad0.72x0.64mm_HandSolder
R65: 49.9R; R_0402_1005Metric
R66: 45.3k; R_0402_1005Metric
R67: 10k; R_0402_1005Metric
U5: TPS562212DRLR; SOT-583-8
U6: MIC5205-5.0YM5; SOT-23-5
U12: SPX3819M5-L-1-8; SOT-23-5

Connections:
+1V8: C63.1, U12.5 (OUT); also elsewhere on the board
+3V3: C12.1, C45.1, C47.1, L1.2, R65.2, U12.1 (IN), U12.3 (EN); also elsewhere on the board
+5V: C52.1, U6.5 (OUT); also elsewhere on the board
GND: C12.2, C31.2, C32.2, C33.2, C34.2, C35.2, C39.2, C40.2, C41.2, C42.2, C44.2, C45.2, C46.2, C47.2, C51.2, C52.2, C62.2, C63.2, R60.1, R62.1, R67.1, U5.4 (GND), U6.2 (GND), U12.2 (GND); also elsewhere on the board
unnamed: C36.1, R63.1
unnamed: C38.1, R64.2
unnamed: R64.1, R65.1, R66.2
unnamed: R63.2, U5.5 (BOOT)
unnamed: R61.2, U5.6 (EN)
unnamed: C38.2, R66.1, R67.2, U5.8 (FB)
unnamed: R62.2, U5.7 (MODE)
unnamed: C36.2, L1.1, U5.3 (SW)
unnamed: C51.1, U6.4 (BP)
unnamed: C62.1, U12.4 (BP)
PG_3V3: R60.2, U5.1 (PG/SS)
VBAT: C31.1, C32.1, C33.1, C34.1, C35.1, C39.1, C40.1, C41.1, C42.1, C44.1, C46.1, R61.1, U5.2 (VIN), U6.1 (IN), U6.3 (EN); also elsewhere on the board

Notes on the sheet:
Vin = 4.2 - 18V Vout = 3.3V Iout (MAX) = 2A The switching frequency is 1.2Mhz The output voltage soft-start time is 2 ms.
1V8 LDO
5V LDO
3V3 Buck
Input Filtering

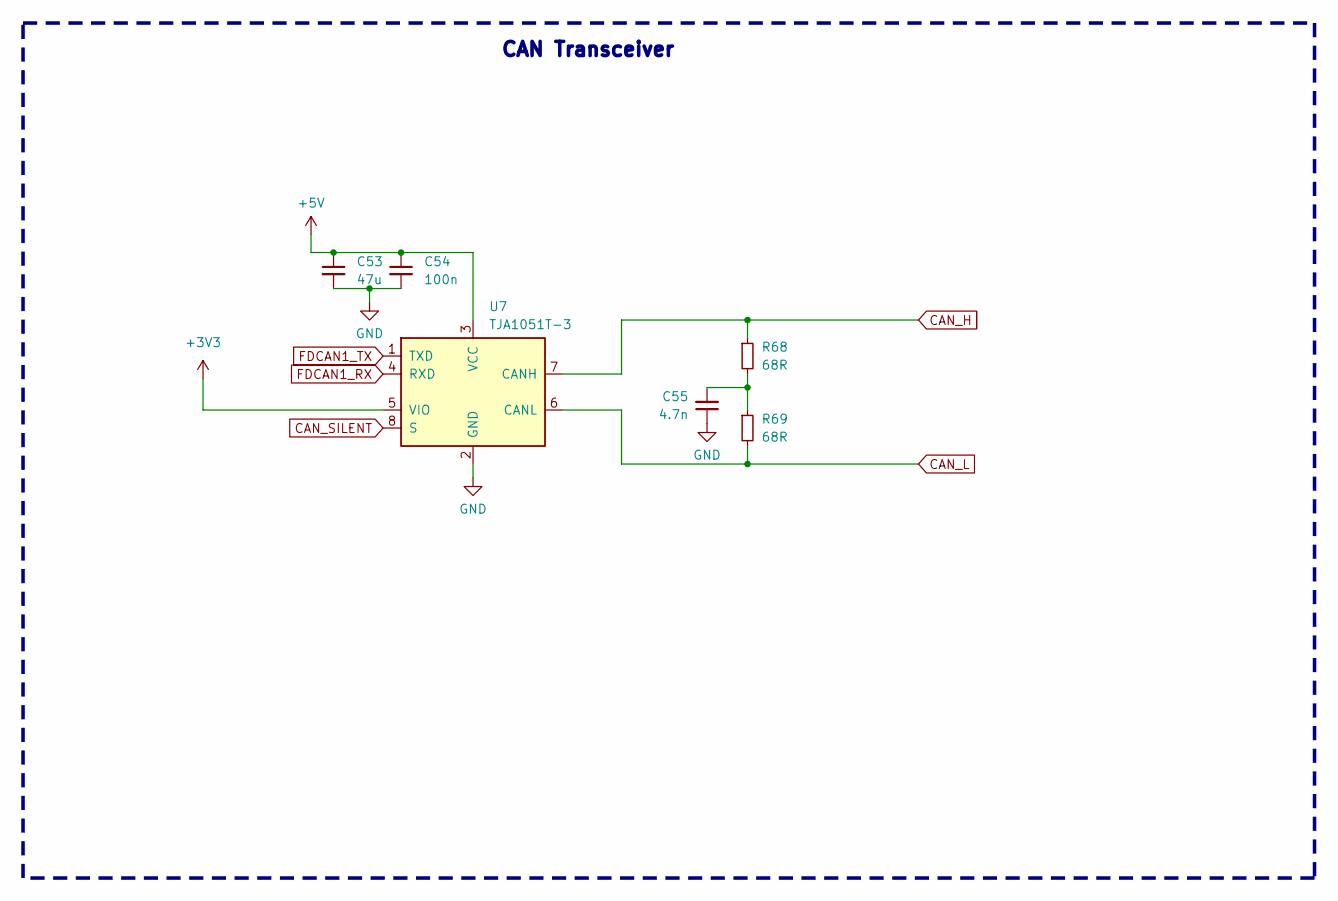
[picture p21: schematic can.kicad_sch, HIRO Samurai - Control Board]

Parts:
C53: 47u; C_0603_1608Metric_Pad1.08x0.95mm_HandSolder
C54: 100n; C_0402_1005Metric_Pad0.74x0.62mm_HandSolder
C55: 4.7n; C_0402_1005Metric_Pad0.74x0.62mm_HandSolder
R68, R69: 68R; C_0603_1608Metric_Pad1.08x0.95mm_HandSolder
U7: TJA1051T-3; SOIC-8_3.9x4.9mm_P1.27mm

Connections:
+3V3: U7.5 (VIO); also elsewhere on the board
+5V: C53.1, C54.1, U7.3 (VCC); also elsewhere on the board
CAN_H: R68.1, U7.7 (CANH); also elsewhere on the board
CAN_L: R69.2, U7.6 (CANL); also elsewhere on the board
CAN_SILENT: U7.8 (S); also elsewhere on the board
FDCAN1_RX: U7.4 (RXD); also elsewhere on the board
FDCAN1_TX: U7.1 (TXD); also elsewhere on the board
GND: C53.2, C54.2, C55.1, U7.2 (GND); also elsewhere on the board
unnamed: C55.2, R68.2, R69.1

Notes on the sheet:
CAN Transceiver

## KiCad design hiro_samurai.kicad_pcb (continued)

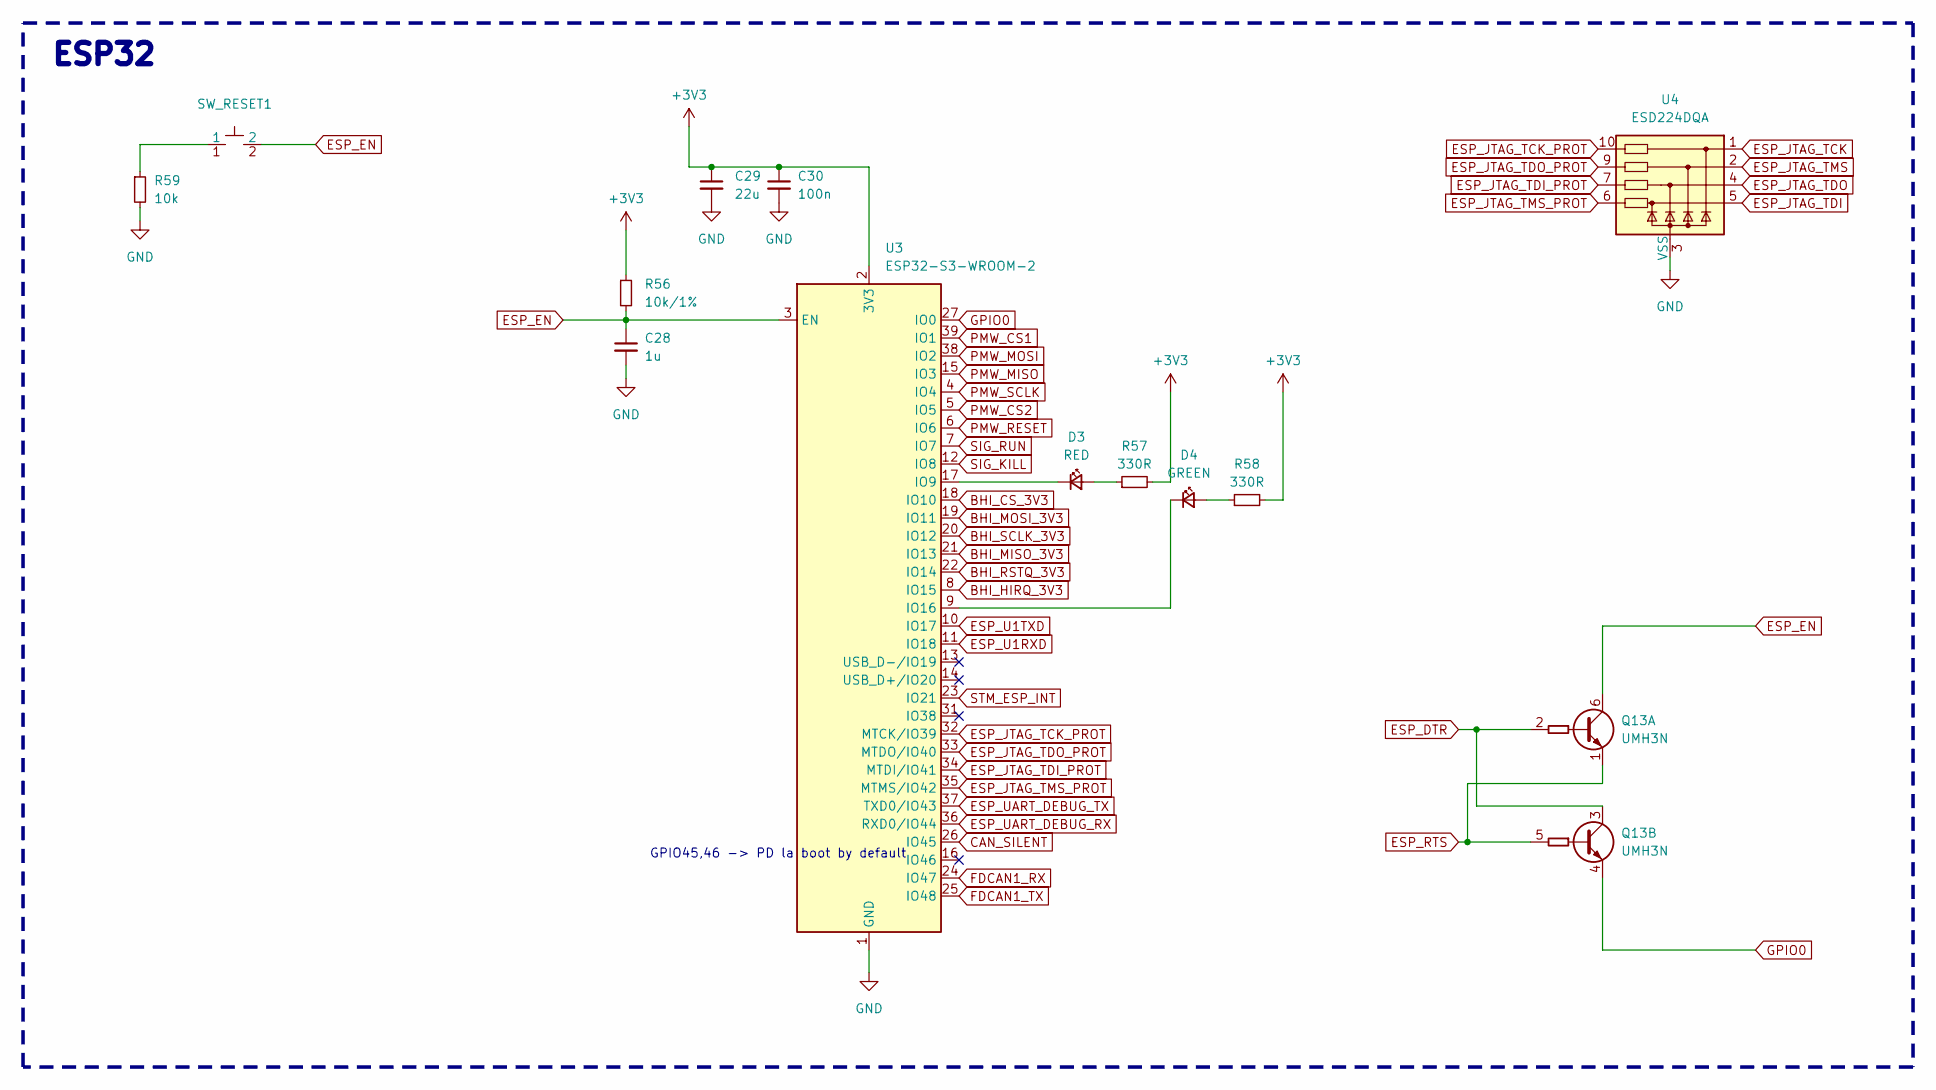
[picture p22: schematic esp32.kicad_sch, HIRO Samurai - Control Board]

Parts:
C28: 1u; C_0402_1005Metric_Pad0.74x0.62mm_HandSolder
C29: 22u; C_0603_1608Metric_Pad1.08x0.95mm_HandSolder
C30: 100n; C_0402_1005Metric_Pad0.74x0.62mm_HandSolder
D3: RED; LED_0603_1608Metric_Pad1.05x0.95mm_HandSolder
D4: GREEN; LED_0603_1608Metric_Pad1.05x0.95mm_HandSolder
Q13: UMH3N; SOT-363_SC-70-6
R56: 10k/1%; R_0402_1005Metric_Pad0.72x0.64mm_HandSolder
R57, R58: 330R; R_0402_1005Metric_Pad0.72x0.64mm_HandSolder
R59: 10k; R_0402_1005Metric_Pad0.72x0.64mm_HandSolder
SW_RESET1: TL1017AABF160QG
U3: ESP32-S3-WROOM-2
U4: ESD224DQA; Diodes_UDFN-10_1.0x2.5mm_P0.5mm

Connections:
+3V3: C29.1, C30.1, R56.1, R57.2, R58.2, U3.2 (3V3); also elsewhere on the board
BHI_CS_3V3: U3.18 (IO10); also elsewhere on the board
BHI_HIRQ_3V3: U3.8 (IO15); also elsewhere on the board
BHI_MISO_3V3: U3.21 (IO13); also elsewhere on the board
BHI_MOSI_3V3: U3.19 (IO11); also elsewhere on the board
BHI_RSTQ_3V3: U3.22 (IO14); also elsewhere on the board
BHI_SCLK_3V3: U3.20 (IO12); also elsewhere on the board
CAN_SILENT: U3.26 (IO45); also elsewhere on the board
ESP_DTR: Q13.2 (B1), Q13.3 (C2); also elsewhere on the board
ESP_EN: C28.1, Q13.6 (C1), R56.2, SW_RESET1.2, U3.3 (EN); also elsewhere on the board
ESP_JTAG_TCK: U4.1; also elsewhere on the board
ESP_JTAG_TCK_PROT: U3.32 (MTCK/IO39), U4.10
ESP_JTAG_TDI: U4.5; also elsewhere on the board
ESP_JTAG_TDI_PROT: U3.34 (MTDI/IO41), U4.7
ESP_JTAG_TDO: U4.4; also elsewhere on the board
ESP_JTAG_TDO_PROT: U3.33 (MTDO/IO40), U4.9
ESP_JTAG_TMS: U4.2; also elsewhere on the board
ESP_JTAG_TMS_PROT: U3.35 (MTMS/IO42), U4.6
ESP_RTS: Q13.1 (E1), Q13.5 (B2); also elsewhere on the board
ESP_U1RXD: U3.11 (IO18); also elsewhere on the board
ESP_U1TXD: U3.10 (IO17); also elsewhere on the board
ESP_UART_DEBUG_RX: U3.36 (RXD0/IO44); also elsewhere on the board
ESP_UART_DEBUG_TX: U3.37 (TXD0/IO43); also elsewhere on the board
FDCAN1_RX: U3.24 (IO47); also elsewhere on the board
FDCAN1_TX: U3.25 (IO48); also elsewhere on the board
GND: C28.2, C29.2, C30.2, R59.2, U3.1 (GND), U3.40 (GND), U3.41 (GND), U4.3 (VSS), U4.8 (VSS); also elsewhere on the board
GPIO0: Q13.4 (E2), U3.27 (IO0)
unnamed: D3.2 (A), R57.1
unnamed: D3.1 (K), U3.17 (IO9)
unnamed: D4.2 (A), R58.1
unnamed: D4.1 (K), U3.9 (IO16)
unnamed: R59.1, SW_RESET1.1
PMW_CS1: U3.39 (IO1); also elsewhere on the board
PMW_CS2: U3.5 (IO5); also elsewhere on the board
PMW_MISO: U3.15 (IO3); also elsewhere on the board
PMW_MOSI: U3.38 (IO2); also elsewhere on the board
PMW_RESET: U3.6 (IO6); also elsewhere on the board
PMW_SCLK: U3.4 (IO4); also elsewhere on the board
SIG_KILL: U3.12 (IO8); also elsewhere on the board
SIG_RUN: U3.7 (IO7); also elsewhere on the board
STM_ESP_INT: U3.23 (IO21); also elsewhere on the board

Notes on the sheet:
GPIO45,46 -> PD la boot by default
ESP32

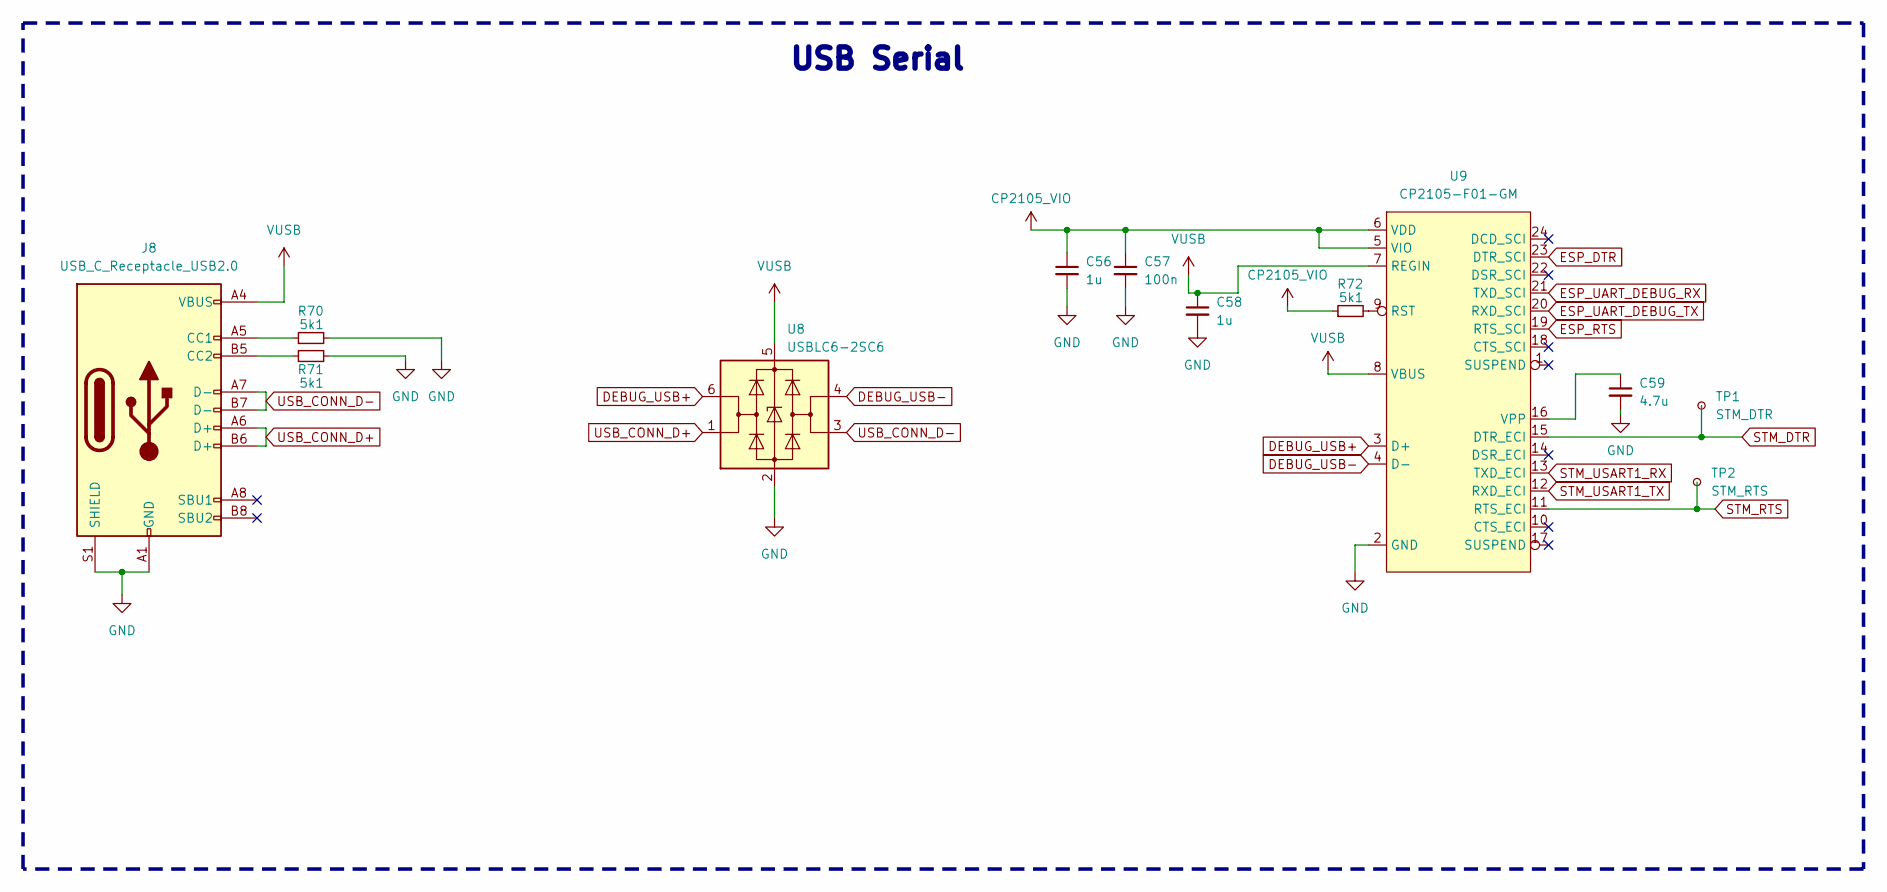
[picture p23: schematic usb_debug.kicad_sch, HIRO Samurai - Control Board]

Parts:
C56, C58: 1u; C_0402_1005Metric_Pad0.74x0.62mm_HandSolder
C57: 100n; C_0402_1005Metric_Pad0.74x0.62mm_HandSolder
C59: 4.7u; C_0402_1005Metric_Pad0.74x0.62mm_HandSolder
J8: USB_C_Receptacle_USB2.0; USB_C_Receptacle_GCT_USB4115-03-C
R70, R71, R72: 5k1; R_0402_1005Metric_Pad0.72x0.64mm_HandSolder
TP1: STM_DTR; TestPoint_Pad_D1.0mm
TP2: STM_RTS; TestPoint_Pad_D1.0mm
U8: USBLC6-2SC6; SOT-23-6
U9: CP2105-F01-GM; QFN-24-1EP_4x4mm_P0.5mm_EP2.7x2.7mm

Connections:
CP2105_VIO: C56.1, C57.1, R72.1, U9.5 (VIO), U9.6 (VDD)
DEBUG_USB+: U8.6 (I/O1), U9.3 (D+)
DEBUG_USB-: U8.4 (I/O2), U9.4 (D-)
ESP_DTR: U9.23 (DTR_SCI); also elsewhere on the board
ESP_RTS: U9.19 (RTS_SCI); also elsewhere on the board
ESP_UART_DEBUG_RX: U9.21 (TXD_SCI); also elsewhere on the board
ESP_UART_DEBUG_TX: U9.20 (RXD_SCI); also elsewhere on the board
GND: C56.2, C57.2, C58.2, C59.2, J8.A1 (GND), J8.A12 (GND), J8.B1 (GND), J8.B12 (GND), J8.S1 (SHIELD), R70.2, R71.2, U8.2 (GND), U9.2 (GND); also elsewhere on the board
unnamed: J8.A5 (CC1), R70.1
unnamed: J8.B5 (CC2), R71.1
unnamed: R72.2, U9.9 (RST)
unnamed: C59.1, U9.16 (VPP)
STM_DTR: TP1.1, U9.15 (DTR_ECI)
STM_RTS: TP2.1, U9.11 (RTS_ECI)
STM_USART1_RX: U9.13 (TXD_ECI); also elsewhere on the board
STM_USART1_TX: U9.12 (RXD_ECI); also elsewhere on the board
USB_CONN_D+: J8.A6 (D+), J8.B6 (D+), U8.1 (I/O1)
USB_CONN_D-: J8.A7 (D-), J8.B7 (D-), U8.3 (I/O2)
VUSB: C58.1, J8.A4 (VBUS), J8.A9 (VBUS), J8.B4 (VBUS), J8.B9 (VBUS), U8.5 (VBUS), U9.7 (REGIN), U9.8 (VBUS)

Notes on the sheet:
USB Serial

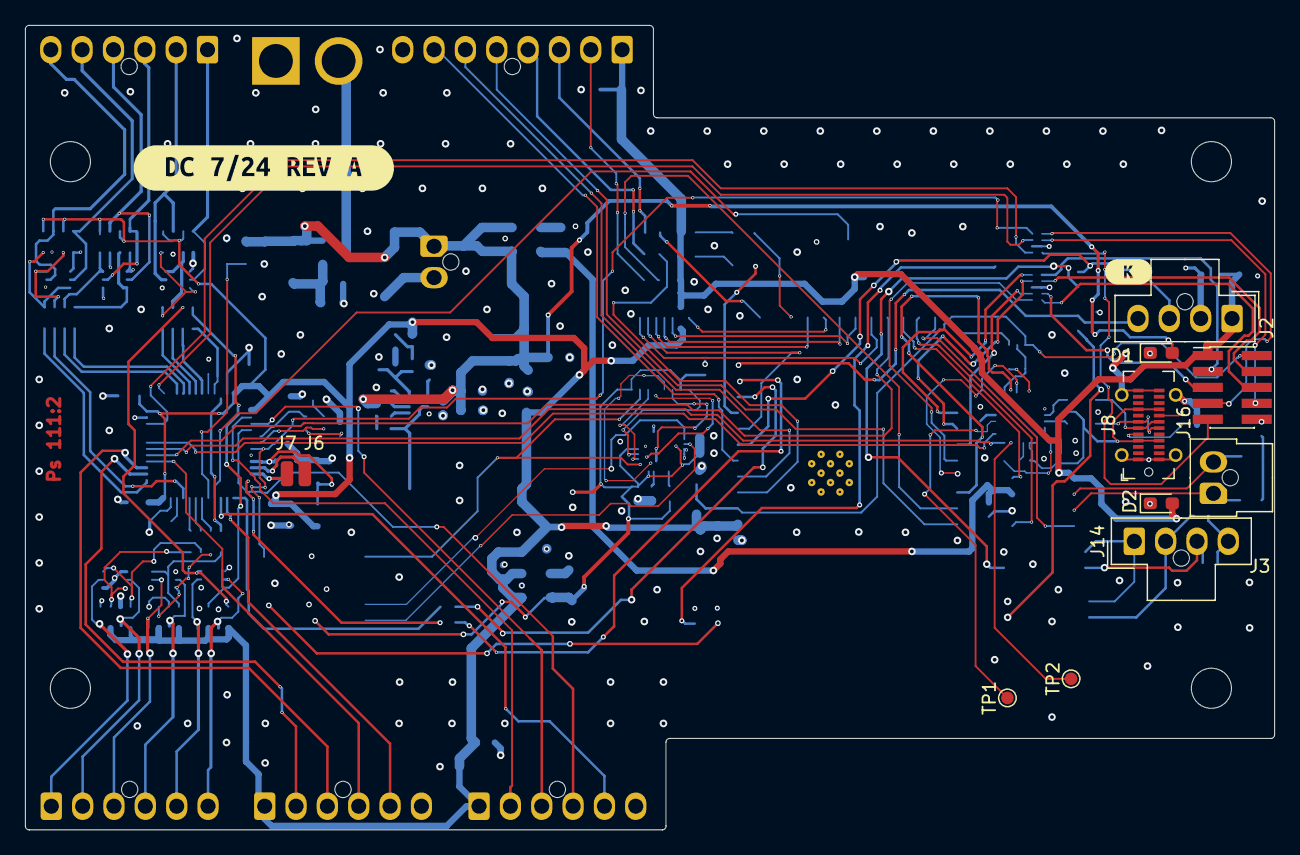
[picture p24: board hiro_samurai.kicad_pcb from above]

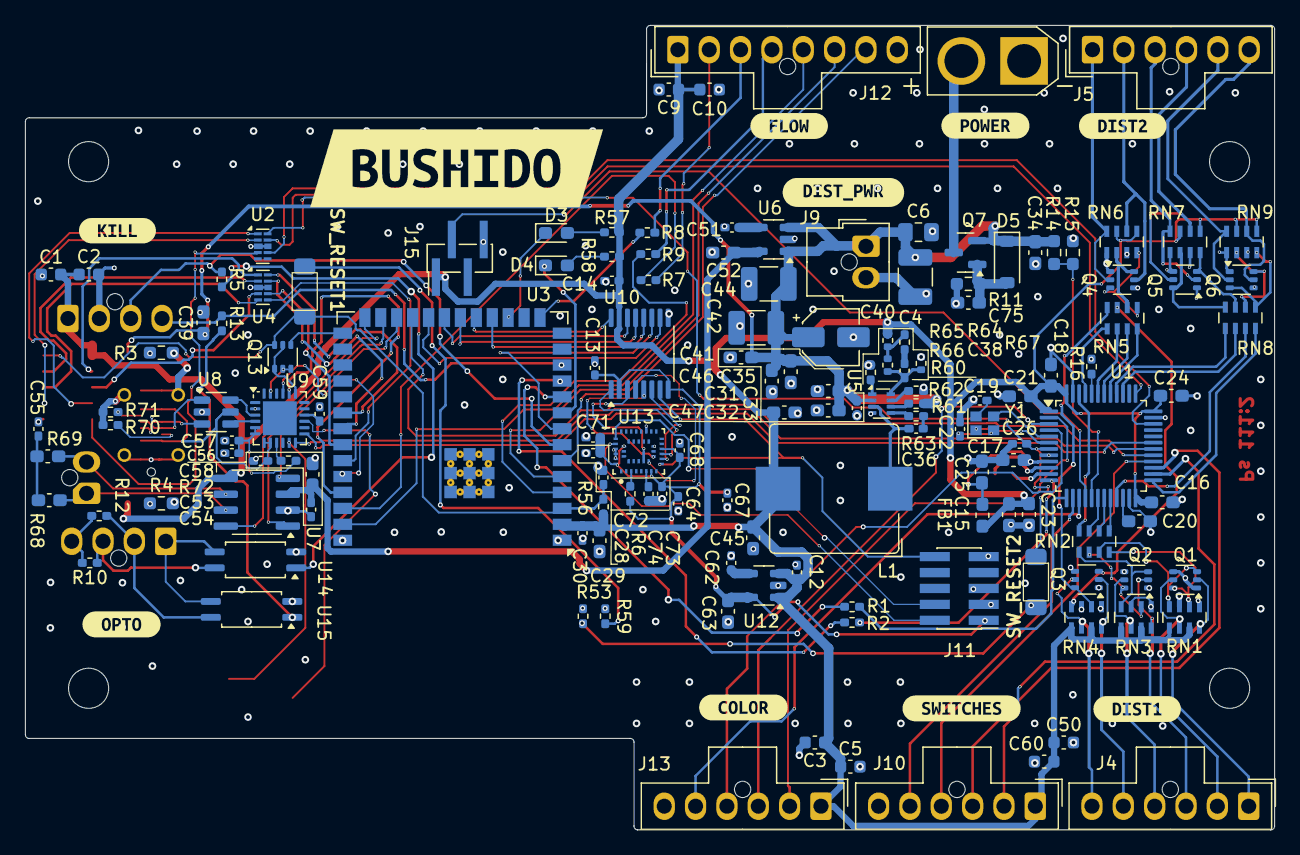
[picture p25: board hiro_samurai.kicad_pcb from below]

Board: 4 copper layers, 99.6 x 64.2 mm, 171 parts (154 on the bottom side), 159 nets.

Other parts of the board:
kibuzzard-66A557E3: G***; kibuzzard-66A557E3
kibuzzard-66A558AF: G***; kibuzzard-66A558AF
kibuzzard-66A558D5: G***; kibuzzard-66A558D5
kibuzzard-66A5583A: G***; kibuzzard-66A5583A
kibuzzard-66A5585D: G***; kibuzzard-66A5585D
kibuzzard-66A5588A: G***; kibuzzard-66A5588A
kibuzzard-66A55516: G***; kibuzzard-66A55516
kibuzzard-66A55816: G***; kibuzzard-66A55816
kibuzzard-66A55828: G***; kibuzzard-66A55828
kibuzzard-66A55877: G***; kibuzzard-66A55877
kibuzzard-66A55897: G***; kibuzzard-66A55897
kibuzzard-66A68797: G***; kibuzzard-66A68797

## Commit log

2024-07-03 First commit. Schematic done, layout in progress 10%
    [CP2105-F01-GM.STEP, ESP32-S3-WROOM-2-N16R8V--3DModel-STEP-510211.STEP, IMU.kicad_sch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]
2024-07-25 Add files via upload
    Uploaded 3D directory
    [CP2105-F01-GM.STEP, ESP32-S3-WROOM-2-N16R8V--3DModel-STEP-510211.STEP, TL1017AABF260QG.stp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]
2024-07-28 Routing done by @Turlinahi
    [IMU.kicad_sch, User Library-SRP 1038A.step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]
2024-07-28 Add render of board

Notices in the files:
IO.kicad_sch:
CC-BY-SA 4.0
